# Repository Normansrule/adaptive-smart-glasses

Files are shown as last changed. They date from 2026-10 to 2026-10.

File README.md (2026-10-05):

<div align="center">

# 👓 Adaptive Smart Glasses <sup>v0.2</sup>

**Open-source camera-passthrough glasses you can print on a Bambu Lab P1S: a center camera, outward "design" screens, and inner micro-OLED screens.**

    

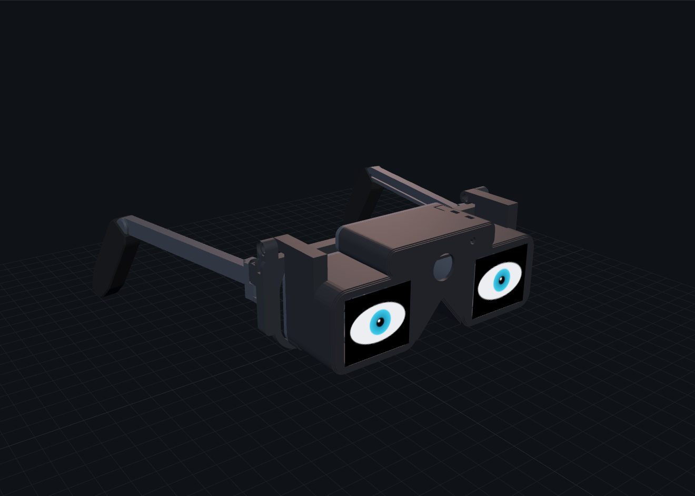
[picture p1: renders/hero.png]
Glasses with the eyes design


**[▶ 3D web app + phone controls](#-web-app--phone-controls)** · [3D files](cad/) · [BOM](docs/BOM.md) · [Pin-by-pin](docs/pinout.md) · [Build guide](docs/manufacturing.md) · [Requirements](docs/requirements.md)

</div>

---

## The idea (Apple Vision Pro meets Google glasses, in a glasses-sized prototype)

| 🎨 Outside: design screens | 👁️ Inside: you see through the camera | 📷 Center camera | 🔋 Light on the face |
|---|---|---|---|
| Two 1.69″ screens on the front show eyes, patterns, rainbow or scrolling text. You pick them from your phone. | Two 0.71″ 1080p micro-OLEDs show the camera view with AR help: zoom, edge highlight, low-light boost, a horizon line and a heads-up display (HUD). | 12 MP, 102° wide, in the bridge. It has a **hardware** power switch and a red **CAMERA LIVE** light. | Heavy compute runs in a **pocket brick** (Raspberry Pi 5) or on the phone. Batteries sit in the **earpieces** as a counterweight. |

| Visor down: passthrough | Visor up: plain glasses |
|---|---|
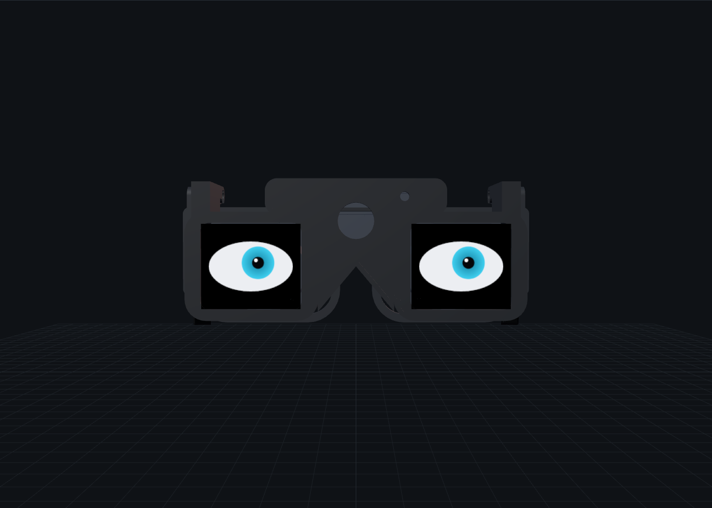
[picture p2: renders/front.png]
front
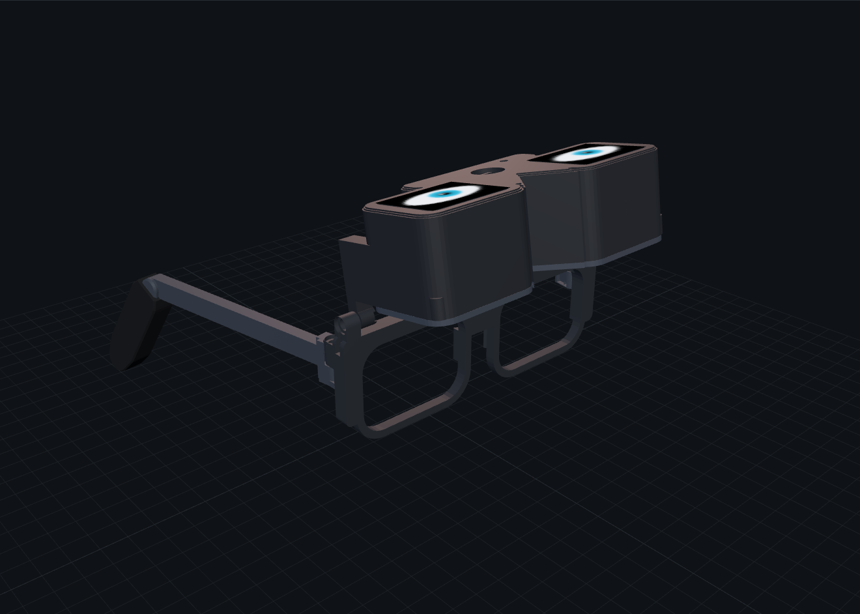
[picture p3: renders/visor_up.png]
visor up
|  |  |

The visor **flips up** on the brow hinge. That's the safety exit: with it up you see normally, and the inner screens switch off.

## Where everything goes

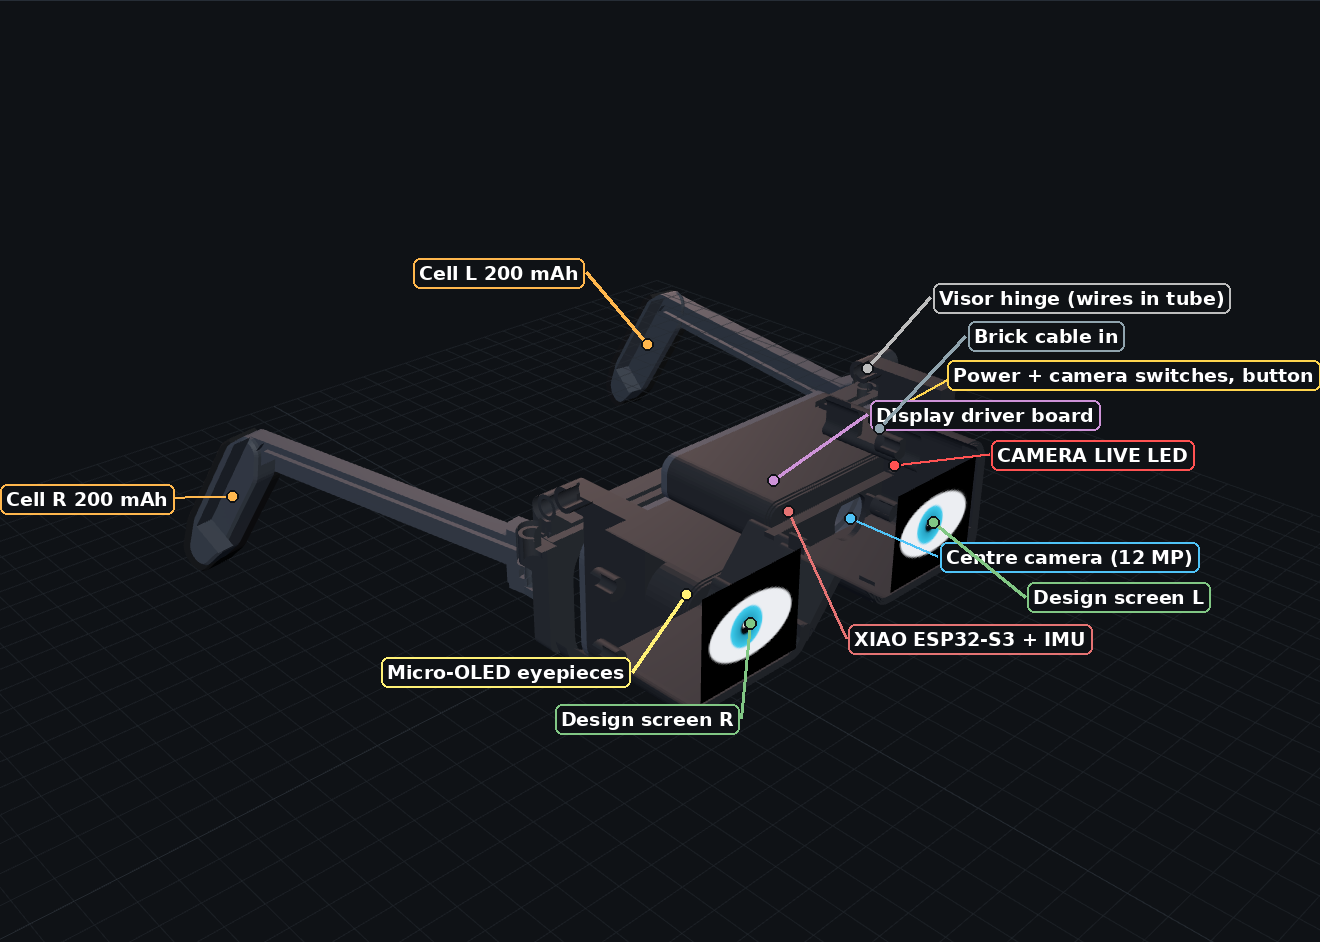
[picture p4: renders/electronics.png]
Electronics map


```
 phone (Web Bluetooth) ──BLE──►  XIAO ESP32-S3 (visor) ──SPI──► 2 outward design screens
                                   │ IMU, hall sensor, button, battery
                                   └──Wi-Fi UDP (head pose, AR mode)──┐
 camera (USB) ───────────────────────────────────────────────────────►├─► pocket brick (Pi 5)
 2 micro-OLEDs + HDMI board ◄────────── HDMI side-by-side 3840×1080 ──┘    passthrough + AR overlay
 earpiece cells (2 × 200 mAh) ──► XIAO  ·  brick power bank ──USB 5 V──► camera + display board
```

## Build it

| Step | What | Details |
|:-:|---|---|
| 1 | 🖨️ **Print** the coupon, tune, then plates 1–3 (7 parts, no supports) | [`cad/plates/`](cad/plates) · [print settings](cad/print_manifest.csv) |
| 2 | 🧪 **Bench test:** flash the XIAO and check the self-test and the designs on both screens | [`firmware/glasses_mcu`](firmware/glasses_mcu) |
| 3 | 🧠 **Brick:** run passthrough on a monitor first | [`brick/`](brick) |
| 4 | 🔭 **Optics** *(experimental)*: micro-OLED kit at side-by-side 3840×1080, then set focus and eye relief | [manufacturing §4](docs/manufacturing.md) |
| 5 | 🧩 **Assemble:** visor, 4 brass hinge tubes, earpiece cells, grips | [assembly](docs/README_CAD.md) |
| 6 | ✅ **Safety + QA:** unplug the camera and you should get a red screen in under 0.25 s; flip the visor up and the screens go dark | [QA sheet](docs/manufacturing.md) |

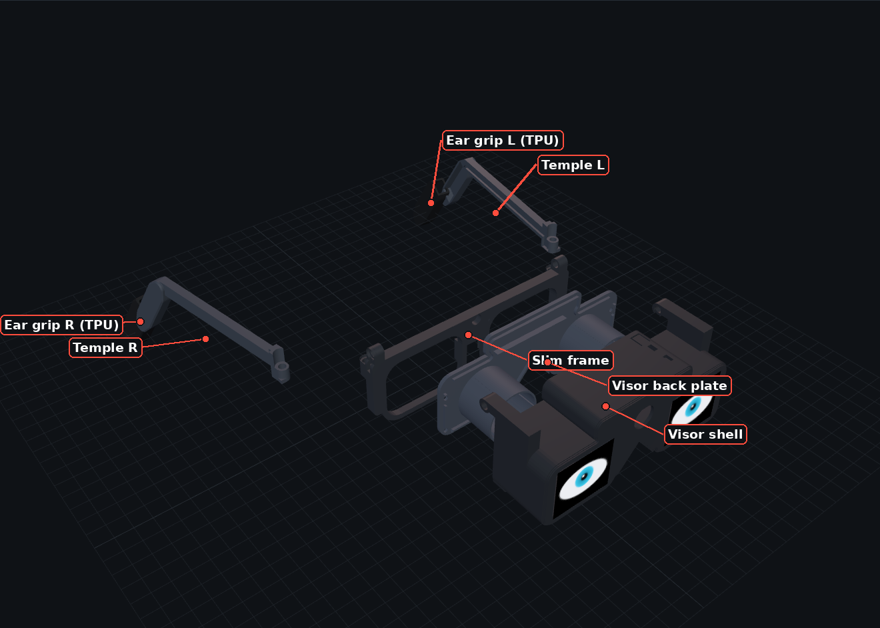
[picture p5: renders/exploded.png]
Exploded view


## Wiring (every pin: [`docs/pinout.md`](docs/pinout.md) · machine-readable: [`hardware/netlist.csv`](hardware/netlist.csv))

<details open><summary><b>Power + camera privacy</b></summary>

Power wiring
</details>
<details><summary><b>Signals: screens, camera, sensors</b></summary>

Signal wiring
</details>

| XIAO pin | Net | | XIAO pin | Net |
|---|---|---|---|---|
| D0 / D1 | CS left / right screen | | D6 | screen backlight (PWM) |
| D2 | screen DC (shared) | | D7 | visor hall switch |
| D3 | battery sense ½ | | D8 / D10 | SPI clock / data (shared) |
| D4 / D5 | I²C → IMU | | D9 | action button |

## Printed parts (7 + coupon)

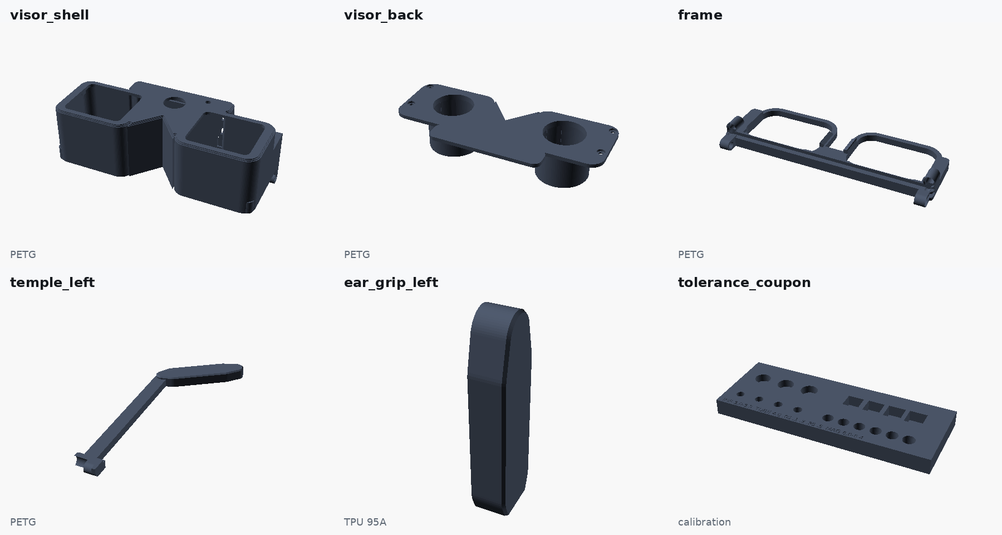
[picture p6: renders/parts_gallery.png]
Parts gallery


| Plate | Parts | Material |
|---|---|---|
| [`plate_0`](cad/plates/plate_0_tolerance_coupon.3mf) | Tolerance coupon (print first) | PETG |
| [`plate_1`](cad/plates/plate_1_frame_temples_petg.3mf) | Slim frame, 2 temples | PETG |
| [`plate_2`](cad/plates/plate_2_visor_petg.3mf) | Visor shell, visor back plate | black PETG |
| [`plate_3`](cad/plates/plate_3_tpu_grips.3mf) | 2 ear grips (they also close the battery bays) | TPU 95A |

## Bill of Materials (BOM)

| Group | ≈ Cost | Main parts |
|---|---:|---|
| **Glasses** | **$854** | 0.71″ 1080p micro-OLED dual kit with eyepieces ($660) · 2× Waveshare 1.69″ screens · Arducam 12 MP USB camera · XIAO ESP32-S3 · LSM6DSOX IMU · hall switch + magnet · 2× 200 mAh cells · 2 slide switches, button, LED · brass tubes, inserts, cable |
| **Pocket brick** | **$220** | Raspberry Pi 5 · 2-port power bank · microSD |
| **Phone** | $0 | Chrome + this repo's web app |

Full list with links: [`docs/BOM.md`](docs/BOM.md). A cheaper 0.49″ display route is listed as an option.

## Honest status

| Part | Status |
|---|---|
| Printed parts | 🟢 **PROTOTYPE-READY**: watertight, no collisions down or up, temples fold, no supports |
| Visor firmware (designs, BLE, IMU, Wi-Fi) | 🟢 compiles cleanly (ESP-IDF 5.5), not yet run on hardware |
| Brick passthrough | 🟡 **EXPERIMENTAL**: pipeline tested with synthetic frames. Expect 60–120 ms latency at 30 fps, mono (same image to both eyes) |
| Optics fit | 🟡 **EXPERIMENTAL**: eyepiece and driver-board sizes are `[MEASURE]` in [`cad/config.scad`](cad/config.scad) |
| Weight | ≈ 150 g (about 60 g printed + 90 g electronics). That's lighter than a headset but heavier than glasses (25–50 g). |

> ⚠️ **Passthrough safety:** with the visor down, you see only what the camera shows. Use it seated or walking slowly. **Never drive, cycle or use stairs with the visor down.** If the camera stalls, the brick shows a red **LIFT VISOR** screen. The camera can't be turned on in software, and the CAMERA LIVE light can't be hidden. Respect people around you.

## 🌐 Web app + phone controls

GitHub Pages hosts the 3D viewer (explode view, visor flip, live design preview, downloads, BOM, wiring) and a **Glasses** tab. In Chrome it uses Web Bluetooth to change the designs, text, brightness and AR mode on the real glasses. Click **Install app** to use it offline. Run it locally with `python3 -m http.server 8000`.

## Edit and rebuild

```bash
sudo apt install -y openscad python3 zip
nano cad/config.scad                 # IPD, head width, module sizes, tolerances
./tools/build.sh                     # STL, 3MF, plates, viewer meshes, BOM, netlist, diagrams
python3 tools/check_fit.py           # collision checks: visor down/up, temple fold
./tools/package_release.sh v0.2.1    # fabrication zip for a GitHub release
```

Licences: hardware **CERN-OHL-S-2.0**, software **MIT**, docs **CC BY-SA 4.0** ([`LICENSES/`](LICENSES/README.md)). The v0.1 camera-free design is in the git history and the v0.1.0 release.

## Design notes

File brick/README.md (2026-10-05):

# Pocket brick: Raspberry Pi 5 (EXPERIMENTAL)

```
camera (USB) ─► passthrough.py ─► enhance (normal / zoom / edges / low-light) ─► HUD ─► SBS 3840×1080 ─► HDMI ─► visor
visor XIAO ──Wi-Fi UDP :5005 (head pose, battery, visor state, AR mode)──► passthrough.py
```

```bash
bash brick/setup_brick.sh          # OpenCV + "ASG-BRICK" hotspot (password glasses123, gateway 10.42.0.1)
python3 brick/passthrough.py       # fullscreen on the HDMI output; press q to quit
python3 brick/passthrough.py --demo --frames 30 --out test.png   # no hardware: synthetic check
```

**Fail-safes:**
- No camera frame for 250 ms: red **LIFT VISOR** screen.
- Visor up: black screen.

**Privacy:** nothing is saved, and there is no face recognition. Expect 60–120 ms latency. Use it seated first.

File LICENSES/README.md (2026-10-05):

# Licensing

| What | Licence | Files |
|---|---|---|
| Hardware design | **CERN-OHL-S-2.0** (strongly reciprocal: modified versions must stay open) | `cad/`, `hardware/`, `models/`, `renders/` |
| Software | **MIT** | `firmware/`, `brick/`, `tools/`, `app.js`, `index.html`, `style.css`, `sw.js` |
| Documentation | **CC BY-SA 4.0** | `docs/`, `README.md` |
| three.js (vendored) | MIT, © three.js authors | `vendor/three/` |

Third-party modules in the BOM (Seeed, SparkFun, Adafruit, Bosch, Edmund Optics …) belong to their makers. This project only references them.

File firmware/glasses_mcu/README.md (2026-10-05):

# Visor firmware: XIAO ESP32-S3 (ESP-IDF 5.5)

| Feature | File |
|---|---|
| Two outward design screens (eyes, rings, rainbow, scrolling text, off), rendered in 40-line bands over SPI | `main/designs.c` |
| Phone control over BLE: GATT service `7a1e0000-5c3b-4c55-9b1d-a5e0a5e0a5e0` | `main/ble.c` |
| Head pose and state to the brick: Wi-Fi to the `ASG-BRICK` hotspot, UDP 44-byte packets at 100 Hz | `main/net.c` |
| IMU (LSM6DSOX), visor hall switch, action button, battery sense, boot self-test | `main/main.c` |

**Status:** compiles cleanly against ESP-IDF v5.5.1 for the esp32s3. Not yet run on finished hardware. The screen mirroring (`esp_lcd_panel_mirror`) and IMU axis signs need checking on the bench.

**Flash the prebuilt image** (no toolchain needed):
```bash
pip install esptool
esptool.py --chip esp32s3 write_flash 0x0 prebuilt/asg_glasses_mcu_merged.bin
```

**Build from source:**
```bash
. ~/esp/esp-idf-v5.5.5/export.sh          # or your ESP-IDF 5.5 path
idf.py set-target esp32s3
idf.py menuconfig    # optional: "Adaptive Smart Glasses" menu (hotspot SSID/password, brick IP/port)
idf.py build flash monitor
```

**Button:** a short press cycles designs. Hold it for at least 1 s to turn the designs off.

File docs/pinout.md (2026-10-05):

# Pin-by-pin connections

Generated by `tools/netlist.py` from the same table as `hardware/netlist.csv` and the diagrams. Edit the script, not this file.

Power and privacy wiring

Signal wiring

## Board prep (do this before wiring)

| Ref | Pin / item | Action |
|---|---|---|
| U5 | RST | tie to 3V3 (the firmware sends a software reset) |
| U6 | RST | tie to 3V3 |
| U1 | D3 | ADC: VBAT/2 |
| U7 | 5V in | power the HDMI board from VBUS, never from the XIAO 3V3 |
| BT1 | before joining | charge both cells to 4.2 V separately, then wire them in parallel |

## Every module, every pin

### J1 · Brick cable
*micro-HDMI->HDMI + USB 4-core, braided* · Enters visor crest, left side

| Pin | Net | Connects to | Wire |
|---|---|---|---|
| USB VBUS | `VBUS_5V` | D2.anode, SW2.COM, U7.5V in | USB red |
| USB GND / HDMI shell | `GND` | BT1.-, BT2.-, U1.GND + BAT- pad, R3.2, D1.cathode, U2.GND, U3.GND, U4.GND, U5.GND, U6.GND, U7.GND, SW3.pin 2 | 28 AWG black |
| USB D+ | `USB_D+` | U2.D+ | USB green |
| USB D- | `USB_D-` | U2.D- | USB white |
| HDMI | `HDMI` | U7.HDMI in | HDMI cable |

### BT1 · Cell LEFT
*Protected 1S LiPo 501040 200 mAh* · Left earpiece

| Pin | Net | Connects to | Wire |
|---|---|---|---|
| + | `BAT+` | BT2.+, SW1.COM | 28 AWG red |
| - | `GND` | BT2.-, J1.USB GND / HDMI shell, U1.GND + BAT- pad, R3.2, D1.cathode, U2.GND, U3.GND, U4.GND, U5.GND, U6.GND, U7.GND, SW3.pin 2 | 28 AWG black |

### BT2 · Cell RIGHT
*Protected 1S LiPo 501040 200 mAh* · Right earpiece

| Pin | Net | Connects to | Wire |
|---|---|---|---|
| + | `BAT+` | BT1.+, SW1.COM | 28 AWG red |
| - | `GND` | BT1.-, J1.USB GND / HDMI shell, U1.GND + BAT- pad, R3.2, D1.cathode, U2.GND, U3.GND, U4.GND, U5.GND, U6.GND, U7.GND, SW3.pin 2 | 28 AWG black |

### SW1 · Main power
*Wurth 452403012014 DPDT slide* · Visor crest top

| Pin | Net | Connects to | Wire |
|---|---|---|---|
| COM | `BAT+` | BT1.+, BT2.+ | 28 AWG red |
| throw A | `BAT_SW` | U1.BAT+ pad, R2.1 | local |

### SW2 · Camera kill
*Wurth 452403012014 DPDT slide* · Visor crest top

| Pin | Net | Connects to | Wire |
|---|---|---|---|
| COM | `VBUS_5V` | J1.USB VBUS, D2.anode, U7.5V in | USB red |
| throw A | `CAM_5V` | U2.5V (USB VBUS), R1.1 | local |

### D1 · CAMERA LIVE LED
*3 mm red LED* · Visor front, beside camera

| Pin | Net | Connects to | Wire |
|---|---|---|---|
| anode (long leg) | `LED_A` | R1.2 | local |
| cathode | `GND` | BT1.-, BT2.-, J1.USB GND / HDMI shell, U1.GND + BAT- pad, R3.2, U2.GND, U3.GND, U4.GND, U5.GND, U6.GND, U7.GND, SW3.pin 2 | 28 AWG black |

### R1 · 1k
*1k 1/8 W* · Visor crest

| Pin | Net | Connects to | Wire |
|---|---|---|---|
| 1 | `CAM_5V` | SW2.throw A, U2.5V (USB VBUS) | local |
| 2 | `LED_A` | D1.anode (long leg) | local |

### D2 · 1N5817
*1N5817 Schottky* · Visor crest

| Pin | Net | Connects to | Wire |
|---|---|---|---|
| anode | `VBUS_5V` | J1.USB VBUS, SW2.COM, U7.5V in | USB red |
| cathode (band) | `XIAO_5V` | U1.5V | local |

### U1 · XIAO ESP32-S3
*Seeed XIAO ESP32-S3 (non-Sense)* · Visor bridge, behind camera

| Pin | Net | Connects to | Wire |
|---|---|---|---|
| BAT+ pad | `BAT_SW` | SW1.throw A, R2.1 | local |
| D3 (A2) | `VBAT_DIV` | R2.2, R3.1 | local |
| 5V | `XIAO_5V` | D2.cathode (band) | local |
| GND + BAT- pad | `GND` | BT1.-, BT2.-, J1.USB GND / HDMI shell, R3.2, D1.cathode, U2.GND, U3.GND, U4.GND, U5.GND, U6.GND, U7.GND, SW3.pin 2 | 28 AWG black |
| 3V3 | `3V3` | U3.VIN (Qwiic), U4.VCC, U5.VCC + RST, U6.VCC + RST | local |
| D8 | `SPI_SCK` | U5.CLK, U6.CLK | local |
| D10 | `SPI_MOSI` | U5.DIN, U6.DIN | local |
| D2 | `LCD_DC` | U5.DC, U6.DC | local |
| D0 | `CS_L` | U5.CS | local |
| D1 | `CS_R` | U6.CS | local |
| D6 | `LCD_BL` | U5.BL, U6.BL | local |
| D4 | `SDA` | U3.SDA (Qwiic) | Qwiic blue |
| D5 | `SCL` | U3.SCL (Qwiic) | Qwiic yellow |
| D7 | `HALL` | U4.OUT | local |
| D9 | `BUTTON` | SW3.pin 1 | local |

### R2 · 100k top
*100k 1/8 W* · Visor bridge

| Pin | Net | Connects to | Wire |
|---|---|---|---|
| 1 | `BAT_SW` | SW1.throw A, U1.BAT+ pad | local |
| 2 | `VBAT_DIV` | R3.1, U1.D3 (A2) | local |

### R3 · 100k bottom
*100k 1/8 W* · Visor bridge

| Pin | Net | Connects to | Wire |
|---|---|---|---|
| 1 | `VBAT_DIV` | R2.2, U1.D3 (A2) | local |
| 2 | `GND` | BT1.-, BT2.-, J1.USB GND / HDMI shell, U1.GND + BAT- pad, D1.cathode, U2.GND, U3.GND, U4.GND, U5.GND, U6.GND, U7.GND, SW3.pin 2 | 28 AWG black |

### U2 · Camera
*Arducam IMX708 UVC 102 deg* · Visor centre bridge, front

| Pin | Net | Connects to | Wire |
|---|---|---|---|
| 5V (USB VBUS) | `CAM_5V` | SW2.throw A, R1.1 | local |
| GND | `GND` | BT1.-, BT2.-, J1.USB GND / HDMI shell, U1.GND + BAT- pad, R3.2, D1.cathode, U3.GND, U4.GND, U5.GND, U6.GND, U7.GND, SW3.pin 2 | 28 AWG black |
| D+ | `USB_D+` | J1.USB D+ | USB green |
| D- | `USB_D-` | J1.USB D- | USB white |

### U3 · IMU
*Adafruit 4438 LSM6DSOX* · Visor bridge

| Pin | Net | Connects to | Wire |
|---|---|---|---|
| GND | `GND` | BT1.-, BT2.-, J1.USB GND / HDMI shell, U1.GND + BAT- pad, R3.2, D1.cathode, U2.GND, U4.GND, U5.GND, U6.GND, U7.GND, SW3.pin 2 | 28 AWG black |
| VIN (Qwiic) | `3V3` | U1.3V3, U4.VCC, U5.VCC + RST, U6.VCC + RST | local |
| SDA (Qwiic) | `SDA` | U1.D4 | Qwiic blue |
| SCL (Qwiic) | `SCL` | U1.D5 | Qwiic yellow |

### U4 · Hall switch
*TI DRV5032FA on SOT-23 adapter* · Back of visor bridge, faces brow magnet

| Pin | Net | Connects to | Wire |
|---|---|---|---|
| GND | `GND` | BT1.-, BT2.-, J1.USB GND / HDMI shell, U1.GND + BAT- pad, R3.2, D1.cathode, U2.GND, U3.GND, U5.GND, U6.GND, U7.GND, SW3.pin 2 | 28 AWG black |
| VCC | `3V3` | U1.3V3, U3.VIN (Qwiic), U5.VCC + RST, U6.VCC + RST | local |
| OUT | `HALL` | U1.D7 | local |

### U5 · LCD LEFT
*Waveshare 1.69in 240x280 ST7789V2* · Left pod, front

| Pin | Net | Connects to | Wire |
|---|---|---|---|
| GND | `GND` | BT1.-, BT2.-, J1.USB GND / HDMI shell, U1.GND + BAT- pad, R3.2, D1.cathode, U2.GND, U3.GND, U4.GND, U6.GND, U7.GND, SW3.pin 2 | 28 AWG black |
| VCC + RST | `3V3` | U1.3V3, U3.VIN (Qwiic), U4.VCC, U6.VCC + RST | local |
| CLK | `SPI_SCK` | U1.D8, U6.CLK | local |
| DIN | `SPI_MOSI` | U1.D10, U6.DIN | local |
| DC | `LCD_DC` | U1.D2, U6.DC | local |
| CS | `CS_L` | U1.D0 | local |
| BL | `LCD_BL` | U1.D6, U6.BL | local |

### U6 · LCD RIGHT
*Waveshare 1.69in 240x280 ST7789V2* · Right pod, front

| Pin | Net | Connects to | Wire |
|---|---|---|---|
| GND | `GND` | BT1.-, BT2.-, J1.USB GND / HDMI shell, U1.GND + BAT- pad, R3.2, D1.cathode, U2.GND, U3.GND, U4.GND, U5.GND, U7.GND, SW3.pin 2 | 28 AWG black |
| VCC + RST | `3V3` | U1.3V3, U3.VIN (Qwiic), U4.VCC, U5.VCC + RST | local |
| CLK | `SPI_SCK` | U1.D8, U5.CLK | local |
| DIN | `SPI_MOSI` | U1.D10, U5.DIN | local |
| DC | `LCD_DC` | U1.D2, U5.DC | local |
| CS | `CS_R` | U1.D1 | local |
| BL | `LCD_BL` | U1.D6, U5.BL | local |

### U7 · Micro-OLED board
*Dual 0.71in micro-OLED HDMI driver* · Visor crest bay

| Pin | Net | Connects to | Wire |
|---|---|---|---|
| 5V in | `VBUS_5V` | J1.USB VBUS, D2.anode, SW2.COM | USB red |
| GND | `GND` | BT1.-, BT2.-, J1.USB GND / HDMI shell, U1.GND + BAT- pad, R3.2, D1.cathode, U2.GND, U3.GND, U4.GND, U5.GND, U6.GND, SW3.pin 2 | 28 AWG black |
| HDMI in | `HDMI` | J1.HDMI | HDMI cable |
| FPC L / FPC R | `OLED_FPC` | test pad / no connection | panel flex |

### SW3 · Action button
*Omron B3F-1000 6x6 tact* · Visor crest top flexure

| Pin | Net | Connects to | Wire |
|---|---|---|---|
| pin 2 | `GND` | BT1.-, BT2.-, J1.USB GND / HDMI shell, U1.GND + BAT- pad, R3.2, D1.cathode, U2.GND, U3.GND, U4.GND, U5.GND, U6.GND, U7.GND | 28 AWG black |
| pin 1 | `BUTTON` | U1.D9 | local |

## Harness cut list (wires that cross a hinge)

| Signal | Wire | Cut (mm) | Route |
|---|---|---:|---|
| BAT+ / GND (left cell) | 30 AWG red/black | 230 | BT1 -> earpiece groove -> L temple tube -> frame -> L visor tube -> SW1 |
| BAT+ / GND (right cell) | 30 AWG red/black | 330 | BT2 -> R temple tube -> brow groove -> L visor tube -> SW1 |
| Brick cable | HDMI + USB 4-core | 1500 | Pocket brick -> clip along left temple -> visor crest (left side) |
| LCD harness | 8 x 30 AWG | 120 | U1 (bridge) -> U5 and U6 (shared SCK/MOSI/DC/BL/VCC/GND, own CS) |

Only battery wires cross hinges: each temple tube carries its cell's BAT+ and GND (2 wires), and the left visor tube carries both pairs (4 wires). Everything else lives inside the visor.

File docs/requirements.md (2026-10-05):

# Requirements and verification (v0.2)

Method: **I** = inspection · **A** = analysis/CAD · **T** = test.
Status: ✅ verified in CAD/analysis/compile · 🧪 needs a hardware test · ⏳ not built yet.

> v0.2 deliberately replaces the v0.1 "camera-free" rule (owner's decision, 2026-10). The privacy rules below take its place.

## Privacy
| ID | Requirement | Method | How it's met | Status |
|---|---|---|---|---|
| PRV-1 | The camera can only get power from a physical switch | I/T | SW2 is the only path from VBUS to CAM_5V ([pinout](pinout.md)). Test: SW2 off means the brick sees no USB camera. | 🧪 |
| PRV-2 | The CAMERA LIVE light is on whenever the camera has power, and software can't hide it | A/T | D1 + R1 sit on CAM_5V and nowhere else. | ✅ wiring · 🧪 |
| PRV-3 | No face recognition, and no recording by default | I | `brick/passthrough.py` processes frames in memory and drops them. | ✅ |
| PRV-4 | Outward designs can be turned off at once | T | Long-press the button, or choose Off in the app. Backlight goes to 0. | 🧪 |

## Safety
| ID | Requirement | Method | How it's met | Status |
|---|---|---|---|---|
| SAF-1 | One action restores normal vision | A/T | The visor flips up through 100° with no collisions (`tools/check_fit.py`), and the frame has open lenses. | ✅ CAD · 🧪 |
| SAF-2 | If the camera fails or stalls, warn within 250 ms | T | The brick shows a red LIFT VISOR screen after 250 ms with no frame. | ✅ synthetic · 🧪 |
| SAF-3 | Visor up turns the inner and outer screens off | T | Hall switch (D7) → firmware blanks the designs; the UDP flag → brick shows black. | ✅ code · 🧪 |
| SAF-4 | Never use passthrough while driving, cycling or on stairs | I | README + app warning. Owner's responsibility. | ✅ doc |
| SAF-5 | Battery safety | A/T | Protected cells at 0.25C charge (XIAO 100 mA), away from the skin behind a 1.4 mm wall + TPU grip. | 🧪 |
| SAF-6 | Design animations stay under 3 flashes per second (photosensitivity) | A | Rings ≈ 0.8 Hz, rainbow is a smooth drift, the eyes blink about every 3–5 s. | ✅ |
| SAF-7 | No sharp edges against the skin | I | Chamfered visor, TPU grips, nose pads. Deburr the tubes. | 🧪 |

## Manufacturability
| ID | Requirement | Method | Status |
|---|---|---|---|
| MFG-1 | All parts print on a P1S with no supports | A (`cad/part_stats.json`) | ✅ |
| MFG-2 | All meshes are manifold | A (`tools/postprocess.py`) | ✅ |
| MFG-3 | No collisions: visor at 0/35/70/100°, temple folded to 80° | A (`tools/check_fit.py`) | ✅ |
| MFG-4 | Only battery wires cross hinges, through the brass tubes | A ([pinout](pinout.md)) | ✅ |
| MFG-5 | Firmware builds from a clean checkout | T (`idf.py build`, ESP-IDF 5.5.1) | ✅ |
| MFG-6 | Optics and driver-board pockets match the real parts | I (`[MEASURE]`) | 🧪 |

## Performance targets
| ID | Target | Status |
|---|---|---|
| PRF-1 | Passthrough at ≥ 30 fps, latency ≤ 120 ms (measure by filming a stopwatch through the eyepiece) | 🧪 |
| PRF-2 | Design screens at ≥ 15 fps on both | 🧪 |
| PRF-3 | Head pose to the brick at 100 Hz | ✅ code · 🧪 |
| PRF-4 | Designs-only standby ≥ 1 h on the earpiece cells | 🧪 |

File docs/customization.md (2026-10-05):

# Customization (`cad/config.scad`)

| Parameter | Default | What it does |
|---|---|---|
| `ipd` | 63 | Pupil distance: centers both eyepiece sleeves. **Set this to your own.** |
| `eye_relief` | 17 | Eye-to-eyepiece distance. The visor position follows it. |
| `head_width`, `ear_y`, `ear_droop` | 148, 98, 55° | Temple splay, ear bend, earpiece angle |
| `cell` | [40, 10, 5] | Earpiece battery bay (L × W × T). For an LP401235, use [36, 12, 4]. |
| `eyepiece_d`, `eyepiece_len` | 26, 22 | **[MEASURE]** your eyepieces |
| `hdmi_board` | [45, 28, 7] | **[MEASURE]** the dual micro-OLED driver board |
| `lcd`, `lcd_active` | 39 × 31.5, 32.6 × 28 | Waveshare 1.69″ screen (outline confirmed, thickness [MEASURE]) |
| `cam_board`, `cam_lens_d`, `cam_z` | 24 × 25, 12, 16.4 | Arducam IMX708 UVC board and lens hole |
| `visor_tube_run` | 4.2 | Frame-side visor bore. Smaller means stiffer (holds the visor up). Tune it on the coupon. |
| `visor_up_deg` | 100 | Flip angle checked by `tools/check_fit.py` |
| `tol`, `insert_hole_d`, `tube_hole_glue`, `tube_hole_run` | 0.3, 3.1, 4.05, 4.35 | Print fits. Tune on the coupon. |

After any change, run `./tools/build.sh && python3 tools/check_fit.py`.

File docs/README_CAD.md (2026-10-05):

# CAD: build, print, assemble (v0.2)

Source: `cad/adaptive_smart_glasses.scad` + `cad/config.scad`.
Outputs: `cad/stl/`, `cad/3mf/`, `cad/plates/`, `models/` (web viewer), `cad/part_stats.json`.

```bash
./tools/build.sh                 # all parts (~1 min)
python3 tools/check_fit.py       # collision checks: visor 0/35/70/100 deg, temple fold, shell vs back plate
openscad -D 'part="assembly_up"' cad/adaptive_smart_glasses.scad   # visor-up preview
```

## Parts
| Part | Material | Print orientation | Holds |
|---|---|---|---|
| frame | PETG | front face down | nose pads, temple + visor hinge knuckles, hall magnet |
| temple_left / temple_right | PETG | head face down | slim arm, earpiece battery bay |
| ear_grip_left / ear_grip_right | TPU 95A | entry end down | closes the battery bay, comfort |
| visor_shell | black PETG | front face down | 2 design screens, camera + LED, crest controls, bridge electronics, visor knuckles |
| visor_back | black PETG | eye side down | eyepiece sleeves (at your IPD), driver-board rail |
| tolerance_coupon | PETG | flat | fit tests |

## Checked in CAD
- All parts are watertight and print with no supports.
- No collisions at rest, with the visor at 35, 70 and 100 degrees, or with a temple folded to 80 degrees.
- The visor clears the frame through its whole travel. The hinge axis sits on top of the brow (Y = +3.3 mm, Z = 27.5 mm).

## Hinges
- **Temples:** a vertical brass-tube pin, with that side's cell wires inside it.
- **Visor:** a horizontal brass-tube pin along X at each end.
  - The tube is glued in the visor knuckle and turns snugly in the frame knuckle (4.2 mm bore), so friction holds the visor up.
  - The left tube carries all 4 battery wires.

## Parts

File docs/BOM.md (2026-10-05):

# Bill of Materials (BOM)

Generated from [`../bom.csv`](../bom.csv) by `tools/bom_md.py`. Prices are approximate USD, so verify before ordering.
Status labels: **FINISHED / PROTOTYPE-READY / EXPERIMENTAL**.

## GLASSES ≈ $853.74

| Item | Part | Qty | ≈ $ each | Status | Notes | Change vs brief |
|---|---|---:|---:|---|---|---|
| [0.71in 1920x1080 micro-OLED 3D dual kit: 2 panels + 1 HDMI board for both + 2 OPE07-10X prism eyepieces](https://www.tindie.com/products/microdisplays/micro-oled-dual-display-071-fhd-1080p-1920x1080/) | Sony ECX335S dual kit | 1 | 659.50 | EXPERIMENTAL | One HDMI input drives both eyes, side by side. Panel is 24.24 x 15.62 x 1.54 mm. Measure the optics and board, then set eyepiece_d, eyepiece_len and hdmi_board in config.scad. | NEW: passthrough view |
| [1.69in 240x280 IPS LCD, ST7789V2, SPI](https://www.waveshare.com/1.69inch-lcd-module.htm) | Waveshare 1.69inch LCD Module | 2 | 9.49 | PROTOTYPE-READY | Shows the designs on the front of each lens. 39 x 31.5 mm outline, about 90 mA each. | NEW: designs screens |
| [12MP IMX708 USB UVC camera, 102 deg (120 deg diagonal), fixed focus](https://www.arducam.com/12mp-imx708-usb-uvc-102-wide-angle-fixed-focus-camera-module-3.html) | Arducam IMX708 UVC 102 | 1 | 71.98 | PROTOTYPE-READY | 24 x 25 mm board in the centre bridge. 1080p30 MJPEG for passthrough, 12 MP stills. For 60 fps you need a 38 mm board. | NEW: centre camera |
| [Seeed XIAO ESP32-S3 (non-Sense)](https://wiki.seeedstudio.com/xiao_esp32s3_getting_started/) | XIAO ESP32-S3 | 1 | 7.49 | PROTOTYPE-READY | Drives the outward LCDs, IMU, hall sensor, button, battery sense and LiPo charging. BLE to the phone, Wi-Fi to the brick. | kept |
| [LSM6DSOX 6-DoF IMU, STEMMA QT](https://www.adafruit.com/product/4438) | Adafruit 4438 | 1 | 11.95 | PROTOTYPE-READY | Mounted in the visor bridge, rigid with the displays. | kept |
| [Hall switch, omnipolar, 1.65-5.5 V](https://www.lcsc.com/product-detail/hall-switches_ti-drv5032fadbzr_C140921.html) | TI DRV5032FA (SOT-23) on a SOT-23 adapter | 1 | 1.20 | PROTOTYPE-READY | Detects visor up or down using a magnet in the brow. Visor up turns the inner displays off and blanks the designs. | NEW |
| Neodymium disc magnet 6 x 3 mm N52 | 6x3 N52 | 1 | 0.30 | PROTOTYPE-READY | Press-fit into the brow centre. | NEW |
| [Protected 1S LiPo 5 x 10 x 40 mm, ~200 mAh (or LP401235 4x12x36)](https://www.ebay.com/itm/254701205905) | 501040 PCM | 2 | 6.00 | PROTOTYPE-READY | One per earpiece, as a counterweight. Wired in parallel: charge both to 4.2 V before joining them. Standby only; passthrough runs on cable power. | 1 big cell -> 2 earpiece cells |
| [DPDT slide switch, 300 mA](https://www.mouser.com/c/?q=452403012014) | Wurth 452403012014 | 2 | 2.67 | PROTOTYPE-READY | Switch 1 is main battery power. Switch 2 is the camera power kill: it physically cuts the camera's 5 V supply. | NEW (camera privacy) |
| 3 mm red LED + 1k resistor on the camera 5 V (after the switch) | CAMERA LIVE | 1 | 0.25 | PROTOTYPE-READY | Hardware-tied, so software cannot hide it. It faces forward beside the camera. | NEW |
| [6 x 6 mm tactile switch](https://www.digikey.com/en/products/filter/pushbutton-switches/199) | Omron B3F-1000 | 1 | 0.25 | PROTOTYPE-READY | Action button under the crest flexure: cycle designs, long-press to capture. | kept |
| 2 x 100k (battery sense divider) | 100k | 2 | 0.03 | PROTOTYPE-READY |  | kept |
| [Brass tube 4 mm OD (ID 3.1), 300 mm](https://ksmetals.com/products/br45mm-4) | K&S 9822 | 1 | 9.99 | EXPERIMENTAL | Four 12-13.5 mm pins: 2 temple hinges, 2 visor hinges. Wires run through them. | kept |
| [M2 heat-set inserts + M2x6 screws](https://www.3djake.com/ruthex/threaded-insert-m2-70-pieces) | ruthex M2 x 4 | 1 | 8.50 | PROTOTYPE-READY | 4 inserts hold the back plate. | kept |
| Thin micro-HDMI to HDMI (1.5 m) + USB-A to bare-wire 4-core (1.5 m), braided sleeve |  | 1 | 18.00 | PROTOTYPE-READY | Video in to the HDMI board, plus USB carrying camera data and 5 V for the glasses. Enters the crest on the left side. | NEW |
| [Stick-on silicone nose pads](https://eyeglasssupplystore.com/products/adhesive-silicone-nose-pads) | adhesive D-pads | 1 | 15.95 | PROTOTYPE-READY |  | kept |
| Silicone wire 30 AWG, 1 mm foam tape, Kapton, filament (PETG ~80 g, TPU ~6 g) |  | 1 | 12.00 | PROTOTYPE-READY |  | kept |

## BRICK ≈ $220.00

| Item | Part | Qty | ≈ $ each | Status | Notes | Change vs brief |
|---|---|---:|---:|---|---|---|
| [Raspberry Pi 5 (8 GB) + active cooler](https://www.raspberrypi.com/products/raspberry-pi-5/) | Raspberry Pi 5 | 1 | 175.00 | EXPERIMENTAL | Runs camera passthrough plus the AR overlay, outputs side-by-side 3840x1080 over HDMI, and does local AI. A Pi 5 4 GB also works. | NEW (Vision Pro-style pocket brick) |
| USB-C power bank, 2 outputs, at least 5V/3A |  | 1 | 35.00 | PROTOTYPE-READY | Port 1 powers the Pi. Port 2 powers the glasses 5 V through the USB lead (keeps load off the Pi's 600 mA USB limit). | NEW |
| microSD 64 GB A2 |  | 1 | 10.00 | PROTOTYPE-READY | Raspberry Pi OS 64-bit + brick/ software. | kept |

## PHONE

| Item | Part | Qty | ≈ $ each | Status | Notes | Change vs brief |
|---|---|---:|---:|---|---|---|
| Any phone with Chrome (Android) for the Web Bluetooth controls |  | 0 | 0.00 | PROTOTYPE-READY | Designs, brightness, text and status via the web app's Glasses tab. Heavy AI can run on the phone or the brick. | NEW |

## OPTION

| Item | Part | Qty | ≈ $ each | Status | Notes | Change vs brief |
|---|---|---:|---:|---|---|---|
| [0.49in 1920x1080 micro-OLED + Dual HDMI or Dual Type-C board, x2](https://www.tindie.com/products/oled-modules/049-micro-oled-display-1920x1080-3000nits/) | SeeYA SY049-class | 0 | 135.00 | EXPERIMENTAL | Panel is 15.68 x 9.09 mm. The Dual Type-C board could take video straight from a DisplayPort-capable phone. Board price and size are unconfirmed. | option |

Totals: glasses ≈ $854 · pocket brick ≈ $220 · together ≈ $1074.
Most of the glasses cost is the micro-OLED dual kit ($660). The budget 0.49-inch option is listed under OPTION.

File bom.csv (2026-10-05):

subsystem | item | part_or_example | qty | approx_unit_usd | tier | status | engineering_notes | source_url | change_vs_brief
Inner displays | 0.71in 1920x1080 micro-OLED 3D dual kit: 2 panels + 1 HDMI board for both + 2 OPE07-10X prism eyepieces | Sony ECX335S dual kit | 1 | 659.5 | GLASSES | EXPERIMENTAL | One HDMI input drives both eyes, side by side. Panel is 24.24 x 15.62 x 1.54 mm. Measure the optics and board, then set eyepiece_d, eyepiece_len and hdmi_board in config.scad. | https://www.tindie.com/products/microdisplays/micro-oled-dual-display-071-fhd-1080p-1920x1080/ | NEW: passthrough view
Inner displays (budget) | 0.49in 1920x1080 micro-OLED + Dual HDMI or Dual Type-C board, x2 | SeeYA SY049-class | 0 | 135.0 | OPTION | EXPERIMENTAL | Panel is 15.68 x 9.09 mm. The Dual Type-C board could take video straight from a DisplayPort-capable phone. Board price and size are unconfirmed. | https://www.tindie.com/products/oled-modules/049-micro-oled-display-1920x1080-3000nits/ | option
Outward displays | 1.69in 240x280 IPS LCD, ST7789V2, SPI | Waveshare 1.69inch LCD Module | 2 | 9.49 | GLASSES | PROTOTYPE-READY | Shows the designs on the front of each lens. 39 x 31.5 mm outline, about 90 mA each. | https://www.waveshare.com/1.69inch-lcd-module.htm | NEW: designs screens
Camera | 12MP IMX708 USB UVC camera, 102 deg (120 deg diagonal), fixed focus | Arducam IMX708 UVC 102 | 1 | 71.98 | GLASSES | PROTOTYPE-READY | 24 x 25 mm board in the centre bridge. 1080p30 MJPEG for passthrough, 12 MP stills. For 60 fps you need a 38 mm board. | https://www.arducam.com/12mp-imx708-usb-uvc-102-wide-angle-fixed-focus-camera-module-3.html | NEW: centre camera
MCU | Seeed XIAO ESP32-S3 (non-Sense) | XIAO ESP32-S3 | 1 | 7.49 | GLASSES | PROTOTYPE-READY | Drives the outward LCDs, IMU, hall sensor, button, battery sense and LiPo charging. BLE to the phone, Wi-Fi to the brick. | https://wiki.seeedstudio.com/xiao_esp32s3_getting_started/ | kept
Head tracking | LSM6DSOX 6-DoF IMU, STEMMA QT | Adafruit 4438 | 1 | 11.95 | GLASSES | PROTOTYPE-READY | Mounted in the visor bridge, rigid with the displays. | https://www.adafruit.com/product/4438 | kept
Visor sensor | Hall switch, omnipolar, 1.65-5.5 V | TI DRV5032FA (SOT-23) on a SOT-23 adapter | 1 | 1.2 | GLASSES | PROTOTYPE-READY | Detects visor up or down using a magnet in the brow. Visor up turns the inner displays off and blanks the designs. | https://www.lcsc.com/product-detail/hall-switches_ti-drv5032fadbzr_C140921.html | NEW
Visor sensor | Neodymium disc magnet 6 x 3 mm N52 | 6x3 N52 | 1 | 0.3 | GLASSES | PROTOTYPE-READY | Press-fit into the brow centre. |  | NEW
Batteries | Protected 1S LiPo 5 x 10 x 40 mm, ~200 mAh (or LP401235 4x12x36) | 501040 PCM | 2 | 6.0 | GLASSES | PROTOTYPE-READY | One per earpiece, as a counterweight. Wired in parallel: charge both to 4.2 V before joining them. Standby only; passthrough runs on cable power. | https://www.ebay.com/itm/254701205905 | 1 big cell -> 2 earpiece cells
Power / privacy | DPDT slide switch, 300 mA | Wurth 452403012014 | 2 | 2.67 | GLASSES | PROTOTYPE-READY | Switch 1 is main battery power. Switch 2 is the camera power kill: it physically cuts the camera's 5 V supply. | https://www.mouser.com/c/?q=452403012014 | NEW (camera privacy)
Privacy indicator | 3 mm red LED + 1k resistor on the camera 5 V (after the switch) | CAMERA LIVE | 1 | 0.25 | GLASSES | PROTOTYPE-READY | Hardware-tied, so software cannot hide it. It faces forward beside the camera. |  | NEW
Input | 6 x 6 mm tactile switch | Omron B3F-1000 | 1 | 0.25 | GLASSES | PROTOTYPE-READY | Action button under the crest flexure: cycle designs, long-press to capture. | https://www.digikey.com/en/products/filter/pushbutton-switches/199 | kept
Power | 2 x 100k (battery sense divider) | 100k | 2 | 0.03 | GLASSES | PROTOTYPE-READY |  |  | kept
Hinges | Brass tube 4 mm OD (ID 3.1), 300 mm | K&S 9822 | 1 | 9.99 | GLASSES | EXPERIMENTAL | Four 12-13.5 mm pins: 2 temple hinges, 2 visor hinges. Wires run through them. | https://ksmetals.com/products/br45mm-4 | kept
Fasteners | M2 heat-set inserts + M2x6 screws | ruthex M2 x 4 | 1 | 8.5 | GLASSES | PROTOTYPE-READY | 4 inserts hold the back plate. | https://www.3djake.com/ruthex/threaded-insert-m2-70-pieces | kept
Cable | Thin micro-HDMI to HDMI (1.5 m) + USB-A to bare-wire 4-core (1.5 m), braided sleeve |  | 1 | 18.0 | GLASSES | PROTOTYPE-READY | Video in to the HDMI board, plus USB carrying camera data and 5 V for the glasses. Enters the crest on the left side. |  | NEW
Comfort | Stick-on silicone nose pads | adhesive D-pads | 1 | 15.95 | GLASSES | PROTOTYPE-READY |  | https://eyeglasssupplystore.com/products/adhesive-silicone-nose-pads | kept
Consumables | Silicone wire 30 AWG, 1 mm foam tape, Kapton, filament (PETG ~80 g, TPU ~6 g) |  | 1 | 12.0 | GLASSES | PROTOTYPE-READY |  |  | kept
Brick compute | Raspberry Pi 5 (8 GB) + active cooler | Raspberry Pi 5 | 1 | 175.0 | BRICK | EXPERIMENTAL | Runs camera passthrough plus the AR overlay, outputs side-by-side 3840x1080 over HDMI, and does local AI. A Pi 5 4 GB also works. | https://www.raspberrypi.com/products/raspberry-pi-5/ | NEW (Vision Pro-style pocket brick)
Brick power | USB-C power bank, 2 outputs, at least 5V/3A |  | 1 | 35.0 | BRICK | PROTOTYPE-READY | Port 1 powers the Pi. Port 2 powers the glasses 5 V through the USB lead (keeps load off the Pi's 600 mA USB limit). |  | NEW
Brick storage | microSD 64 GB A2 |  | 1 | 10.0 | BRICK | PROTOTYPE-READY | Raspberry Pi OS 64-bit + brick/ software. |  | kept
Phone | Any phone with Chrome (Android) for the Web Bluetooth controls |  | 0 | 0 | PHONE | PROTOTYPE-READY | Designs, brightness, text and status via the web app's Glasses tab. Heavy AI can run on the phone or the brick. |  | NEW

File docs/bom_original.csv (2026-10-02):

subsystem | item | part_or_example | qty | approx_unit_usd | tier | engineering_notes | source_url
Core MCU | Seeed Studio XIAO ESP32-S3 | XIAO ESP32-S3 | 1 | 7.49 | CORE | BLE/Wi-Fi MCU; use non-Sense version to avoid an unwanted camera. | https://wiki.seeedstudio.com/xiao_esp32s3_getting_started/
Depth sensing | SparkFun Qwiic Mini ToF Imager | VL53L5CX / SEN-19013 | 1 | 25.95 | CORE | 64-zone 8x8 ToF; bridge-mounted; no image camera. | https://www.sparkfun.com/sparkfun-qwiic-mini-tof-imager-vl53l5cx.html
Motion | ICM-42688-P breakout | ICM-42688-P | 1 | 15.0 | CORE | 6-axis IMU; any compact 3.3V I2C breakout is acceptable. | https://www.invensense.tdk.com/en-us/products/6-axis/icm-42688-p
Pressure | BMP390 breakout | BMP390 | 1 | 10.99 | CORE | Pressure trend for flight-mode suggestion; not sole aircraft detector. | https://www.bosch-sensortec.com/en/products/environmental-sensors/pressure-sensors/bmp390
Ambient | SHT40 breakout | SHT40 | 1 | 5.95 | CORE | Ambient temperature/humidity; mount in a ventilated outer pod away from skin. | https://www.adafruit.com/product/4885
Microphone | I2S MEMS microphone breakout | SPH0645LM4H | 1 | 6.95 | CORE | Powered only by physical PTT switch. | https://www.adafruit.com/product/3421
Audio amp | I2S Class-D amplifier | MAX98357A | 2 | 5.95 | CORE | One amp for bone path, one for outward speakers; independent SD control. | https://www.adafruit.com/product/3006
Bone audio | 8 ohm 1 W bone-conduction transducer | 8R 1W | 2 | 8.0 | CORE | Mount near mastoid via compliant TPU carrier; do not clamp hard. | https://www.adafruit.com/product/1674
Open audio | 8 ohm 1–2 W micro speaker | 8R 1-2W | 2 | 4.0 | CORE | Directional/open-ear outward audio; keep volume conservative. | https://www.adafruit.com/category/271
Charging | USB-C Li-ion/LiPo charger with load sharing | BQ24074 breakout | 1 | 14.95 | CORE | External charger preferred; set charge current to match the pack; add NTC. | https://learn.adafruit.com/adafruit-bq24074-universal-usb-dc-solar-charger-breakout
Battery | Protected 1S LiPo 1200 mAh | 3.7V 1200mAh | 1 | 9.95 | CORE | Rear/side pod; use a protected pack from a reputable supplier. | https://www.adafruit.com/category/574
5V regulator | 5V boost converter, >=1 A core mode | TPS61023-class | 1 | 6.0 | CORE | Feeds 5V system/audio rail; media pod uses its own higher-current supply. | https://www.adafruit.com/category/578
Battery thermal | 10k NTC thermistor | 10k NTC | 1 | 1.0 | CORE | Bond to pouch cell; use charger TS/thermistor input when supported. | https://www.adafruit.com/category/66
Privacy control | DPST momentary pushbutton | PTT switch | 1 | 4.0 | CORE | Pole A switches microphone rail; Pole B is MCU PTT sense. | https://www.digikey.com/en/products/filter/pushbutton-switches/199
Power control | SPST/DPST slide switch | MAIN POWER | 1 | 2.0 | CORE | Physical on/off between charger load output and system regulator. | https://www.digikey.com/en/products/filter/slide-switches/213
Privacy indicator | Red LED + 1k resistor | MIC ON | 1 | 0.25 | CORE | Wired directly to switched microphone rail.
Harness | 28–32 AWG silicone wire + JST-SH/Qwiic pigtails | Harness | 1 | 10.0 | CORE | Use strain relief at both hinges.
Fasteners | M2 x 5/6 mm screws + M2 heat-set inserts | M2 | 1 | 8.0 | CORE | Serviceable covers and pods.
Soft grip | 95A TPU + 1–2 mm silicone/memory foam tape | Ear grip | 1 | 8.0 | CORE | Printed TPU shell with replaceable inward foam strip.
Combiner optics | Optical-grade partial reflector / beam splitter | ~30R/70T | 2 | 25.0 | HUD | Do not use printed transparent plastic for final optics.
HUD display | Compact micro-OLED + collimator/driver | 640x400-class | 1 | 99.0 | HUD | Start monocular; controller compatibility must be confirmed before purchase.
HUD optics | Collimating/aspheric lens + adjustable holder | 20–25 mm class | 1 | 20.0 | HUD | Tune focal position and eyebox experimentally.
Media compute | Raspberry Pi Zero 2 W | SC0510 | 1 | 14.99 | MEDIA | Optional H.264 media renderer; core MCU remains safety authority. | https://www.raspberrypi.com/products/raspberry-pi-zero-2-w/
Media display | High-resolution micro-OLED + HDMI/MIPI controller | 720p/1080p class | 1 | 150.0 | MEDIA | Prototype one eye before buying the second display.
Media power | Protected 1S LiPo 2000–3000 mAh + 5V >=2A regulator | rear media pack | 1 | 25.0 | MEDIA | Separate rear pod improves thermal balance; charge with matched safe charger.
Media storage | microSD 32 GB | A1/A2 card | 1 | 7.0 | MEDIA | OS and cached media/translation assets for Pi-based mode.

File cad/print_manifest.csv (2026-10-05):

part | material | tier | orientation | supports | layer_mm | walls | infill | plate_3mf | notes | bbox_mm | solid_mass_g | fits_A1_mini
tolerance_coupon | PETG | print FIRST | flat | none | 0.16 | 4 | 30% gyroid | plate_0 | Tune the insert hole, tube fits (temple 4.05 glue / 4.35 run, visor 4.2 friction) and the magnet pocket, then rebuild. | 82.0x30.0x6.0 | 16.7 | True
frame | PETG | GLASSES | front face down | none | 0.16 | 4 | 30% gyroid | plate_1 | Ream the temple knuckles to 4.35 and the visor knuckles to 4.2 (friction holds the visor up). Press the 6x3 magnet in. | 129.0x50.8x12.8 | 12.6 | True
temple_left | PETG | GLASSES | head face down | none | 0.16 | 4 | 30% gyroid | plate_1 | Drill the knuckle to 4.05 and glue the tube. The cell drops into the earpiece bay from the head side. | 52.6x134.7x6.8 | 7.8 | True
temple_right | PETG | GLASSES | head face down | none | 0.16 | 4 | 30% gyroid | plate_1 | Same as the left temple. | 52.6x134.7x6.8 | 7.8 | True
visor_shell | PETG black | GLASSES | front face down | none | 0.16 | 4 | 25% gyroid | plate_2 | Fit 4 M2 inserts in the back bosses. Visor knuckles: drill to 4.05 and glue the tubes. | 113.0x47.0x42.6 | 30.4 | True
visor_back | PETG black | GLASSES | eye side down | none | 0.16 | 3 | 25% gyroid | plate_2 | The eyepiece sleeves hold the optics with crush ribs. Fits with 4 x M2x6. | 113.0x47.0x24.0 | 14.5 | True
ear_grip_left | TPU 95A | GLASSES | entry end down | none | 0.20 | 3 | 20% gyroid | plate_3 | Slide over the earpiece to close the battery bay. Feed TPU from the external spool. | 9.2x15.6x54.8 | 3.6 | True
ear_grip_right | TPU 95A | GLASSES | entry end down | none | 0.20 | 3 | 20% gyroid | plate_3 | Same as the left grip. | 9.2x15.6x54.8 | 3.6 | True

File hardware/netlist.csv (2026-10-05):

net | ref | module | pin | part | location | wire | net_description
BAT+ | BT1 | Cell LEFT | + | Protected 1S LiPo 501040 200 mAh | Left earpiece | 28 AWG red | Both cells in parallel
BAT+ | BT2 | Cell RIGHT | + | Protected 1S LiPo 501040 200 mAh | Right earpiece | 28 AWG red | Both cells in parallel
BAT+ | SW1 | Main power | COM | Wurth 452403012014 DPDT slide | Visor crest top | 28 AWG red | Both cells in parallel
BAT_SW | SW1 | Main power | throw A | Wurth 452403012014 DPDT slide | Visor crest top | local | Switched battery
BAT_SW | U1 | XIAO ESP32-S3 | BAT+ pad | Seeed XIAO ESP32-S3 (non-Sense) | Visor bridge, behind camera | local | Switched battery
BAT_SW | R2 | 100k top | 1 | 100k 1/8 W | Visor bridge | local | Switched battery
VBAT_DIV | R2 | 100k top | 2 | 100k 1/8 W | Visor bridge | local | Half battery voltage to ADC
VBAT_DIV | R3 | 100k bottom | 1 | 100k 1/8 W | Visor bridge | local | Half battery voltage to ADC
VBAT_DIV | U1 | XIAO ESP32-S3 | D3 (A2) | Seeed XIAO ESP32-S3 (non-Sense) | Visor bridge, behind camera | local | Half battery voltage to ADC
VBUS_5V | J1 | Brick cable | USB VBUS | micro-HDMI->HDMI + USB 4-core, braided | Enters visor crest, left side | USB red | 5 V from the brick / power bank
VBUS_5V | D2 | 1N5817 | anode | 1N5817 Schottky | Visor crest | USB red | 5 V from the brick / power bank
VBUS_5V | SW2 | Camera kill | COM | Wurth 452403012014 DPDT slide | Visor crest top | USB red | 5 V from the brick / power bank
VBUS_5V | U7 | Micro-OLED board | 5V in | Dual 0.71in micro-OLED HDMI driver | Visor crest bay | USB red | 5 V from the brick / power bank
XIAO_5V | D2 | 1N5817 | cathode (band) | 1N5817 Schottky | Visor crest | local | XIAO 5V pin, also charges the cells
XIAO_5V | U1 | XIAO ESP32-S3 | 5V | Seeed XIAO ESP32-S3 (non-Sense) | Visor bridge, behind camera | local | XIAO 5V pin, also charges the cells
CAM_5V | SW2 | Camera kill | throw A | Wurth 452403012014 DPDT slide | Visor crest top | local | Camera power, ONLY with SW2 on
CAM_5V | U2 | Camera | 5V (USB VBUS) | Arducam IMX708 UVC 102 deg | Visor centre bridge, front | local | Camera power, ONLY with SW2 on
CAM_5V | R1 | 1k | 1 | 1k 1/8 W | Visor crest | local | Camera power, ONLY with SW2 on
LED_A | R1 | 1k | 2 | 1k 1/8 W | Visor crest | local | LED current limit
LED_A | D1 | CAMERA LIVE LED | anode (long leg) | 3 mm red LED | Visor front, beside camera | local | LED current limit
GND | BT1 | Cell LEFT | - | Protected 1S LiPo 501040 200 mAh | Left earpiece | 28 AWG black | Common ground
GND | BT2 | Cell RIGHT | - | Protected 1S LiPo 501040 200 mAh | Right earpiece | 28 AWG black | Common ground
GND | J1 | Brick cable | USB GND / HDMI shell | micro-HDMI->HDMI + USB 4-core, braided | Enters visor crest, left side | 28 AWG black | Common ground
GND | U1 | XIAO ESP32-S3 | GND + BAT- pad | Seeed XIAO ESP32-S3 (non-Sense) | Visor bridge, behind camera | 28 AWG black | Common ground
GND | R3 | 100k bottom | 2 | 100k 1/8 W | Visor bridge | 28 AWG black | Common ground
GND | D1 | CAMERA LIVE LED | cathode | 3 mm red LED | Visor front, beside camera | 28 AWG black | Common ground
GND | U2 | Camera | GND | Arducam IMX708 UVC 102 deg | Visor centre bridge, front | 28 AWG black | Common ground
GND | U3 | IMU | GND | Adafruit 4438 LSM6DSOX | Visor bridge | 28 AWG black | Common ground
GND | U4 | Hall switch | GND | TI DRV5032FA on SOT-23 adapter | Back of visor bridge, faces brow magnet | 28 AWG black | Common ground
GND | U5 | LCD LEFT | GND | Waveshare 1.69in 240x280 ST7789V2 | Left pod, front | 28 AWG black | Common ground
GND | U6 | LCD RIGHT | GND | Waveshare 1.69in 240x280 ST7789V2 | Right pod, front | 28 AWG black | Common ground
GND | U7 | Micro-OLED board | GND | Dual 0.71in micro-OLED HDMI driver | Visor crest bay | 28 AWG black | Common ground
GND | SW3 | Action button | pin 2 | Omron B3F-1000 6x6 tact | Visor crest top flexure | 28 AWG black | Common ground
3V3 | U1 | XIAO ESP32-S3 | 3V3 | Seeed XIAO ESP32-S3 (non-Sense) | Visor bridge, behind camera | local | Logic supply from the XIAO
3V3 | U3 | IMU | VIN (Qwiic) | Adafruit 4438 LSM6DSOX | Visor bridge | local | Logic supply from the XIAO
3V3 | U4 | Hall switch | VCC | TI DRV5032FA on SOT-23 adapter | Back of visor bridge, faces brow magnet | local | Logic supply from the XIAO
3V3 | U5 | LCD LEFT | VCC + RST | Waveshare 1.69in 240x280 ST7789V2 | Left pod, front | local | Logic supply from the XIAO
3V3 | U6 | LCD RIGHT | VCC + RST | Waveshare 1.69in 240x280 ST7789V2 | Right pod, front | local | Logic supply from the XIAO
USB_D+ | J1 | Brick cable | USB D+ | micro-HDMI->HDMI + USB 4-core, braided | Enters visor crest, left side | USB green | Camera USB data to the brick
USB_D+ | U2 | Camera | D+ | Arducam IMX708 UVC 102 deg | Visor centre bridge, front | USB green | Camera USB data to the brick
USB_D- | J1 | Brick cable | USB D- | micro-HDMI->HDMI + USB 4-core, braided | Enters visor crest, left side | USB white
USB_D- | U2 | Camera | D- | Arducam IMX708 UVC 102 deg | Visor centre bridge, front | USB white
HDMI | J1 | Brick cable | HDMI | micro-HDMI->HDMI + USB 4-core, braided | Enters visor crest, left side | HDMI cable | Side-by-side 3840x1080 video
HDMI | U7 | Micro-OLED board | HDMI in | Dual 0.71in micro-OLED HDMI driver | Visor crest bay | HDMI cable | Side-by-side 3840x1080 video
SPI_SCK | U1 | XIAO ESP32-S3 | D8 | Seeed XIAO ESP32-S3 (non-Sense) | Visor bridge, behind camera | local | LCD clock (shared)
SPI_SCK | U5 | LCD LEFT | CLK | Waveshare 1.69in 240x280 ST7789V2 | Left pod, front | local | LCD clock (shared)
SPI_SCK | U6 | LCD RIGHT | CLK | Waveshare 1.69in 240x280 ST7789V2 | Right pod, front | local | LCD clock (shared)
SPI_MOSI | U1 | XIAO ESP32-S3 | D10 | Seeed XIAO ESP32-S3 (non-Sense) | Visor bridge, behind camera | local | LCD data (shared)
SPI_MOSI | U5 | LCD LEFT | DIN | Waveshare 1.69in 240x280 ST7789V2 | Left pod, front | local | LCD data (shared)
SPI_MOSI | U6 | LCD RIGHT | DIN | Waveshare 1.69in 240x280 ST7789V2 | Right pod, front | local | LCD data (shared)
LCD_DC | U1 | XIAO ESP32-S3 | D2 | Seeed XIAO ESP32-S3 (non-Sense) | Visor bridge, behind camera | local | Data / command (shared)
LCD_DC | U5 | LCD LEFT | DC | Waveshare 1.69in 240x280 ST7789V2 | Left pod, front | local | Data / command (shared)
LCD_DC | U6 | LCD RIGHT | DC | Waveshare 1.69in 240x280 ST7789V2 | Right pod, front | local | Data / command (shared)
CS_L | U1 | XIAO ESP32-S3 | D0 | Seeed XIAO ESP32-S3 (non-Sense) | Visor bridge, behind camera | local | Select left LCD
CS_L | U5 | LCD LEFT | CS | Waveshare 1.69in 240x280 ST7789V2 | Left pod, front | local | Select left LCD
CS_R | U1 | XIAO ESP32-S3 | D1 | Seeed XIAO ESP32-S3 (non-Sense) | Visor bridge, behind camera | local | Select right LCD
CS_R | U6 | LCD RIGHT | CS | Waveshare 1.69in 240x280 ST7789V2 | Right pod, front | local | Select right LCD
LCD_BL | U1 | XIAO ESP32-S3 | D6 | Seeed XIAO ESP32-S3 (non-Sense) | Visor bridge, behind camera | local | Backlight PWM (shared)
LCD_BL | U5 | LCD LEFT | BL | Waveshare 1.69in 240x280 ST7789V2 | Left pod, front | local | Backlight PWM (shared)
LCD_BL | U6 | LCD RIGHT | BL | Waveshare 1.69in 240x280 ST7789V2 | Right pod, front | local | Backlight PWM (shared)
SDA | U1 | XIAO ESP32-S3 | D4 | Seeed XIAO ESP32-S3 (non-Sense) | Visor bridge, behind camera | Qwiic blue | I2C data
SDA | U3 | IMU | SDA (Qwiic) | Adafruit 4438 LSM6DSOX | Visor bridge | Qwiic blue | I2C data
SCL | U1 | XIAO ESP32-S3 | D5 | Seeed XIAO ESP32-S3 (non-Sense) | Visor bridge, behind camera | Qwiic yellow | I2C clock
SCL | U3 | IMU | SCL (Qwiic) | Adafruit 4438 LSM6DSOX | Visor bridge | Qwiic yellow | I2C clock
HALL | U4 | Hall switch | OUT | TI DRV5032FA on SOT-23 adapter | Back of visor bridge, faces brow magnet | local | Visor down = LOW
HALL | U1 | XIAO ESP32-S3 | D7 | Seeed XIAO ESP32-S3 (non-Sense) | Visor bridge, behind camera | local | Visor down = LOW
BUTTON | SW3 | Action button | pin 1 | Omron B3F-1000 6x6 tact | Visor crest top flexure | local | Action button (pull-up)
BUTTON | U1 | XIAO ESP32-S3 | D9 | Seeed XIAO ESP32-S3 (non-Sense) | Visor bridge, behind camera | local | Action button (pull-up)
OLED_FPC | U7 | Micro-OLED board | FPC L / FPC R | Dual 0.71in micro-OLED HDMI driver | Visor crest bay | panel flex | Panel flex cables
NC / prep | U5 | LCD LEFT | RST | Waveshare 1.69in 240x280 ST7789V2 | Left pod, front |  | tie to 3V3 (the firmware sends a software reset)
NC / prep | U6 | LCD RIGHT | RST | Waveshare 1.69in 240x280 ST7789V2 | Right pod, front |  | tie to 3V3
NC / prep | U1 | XIAO ESP32-S3 | D3 | Seeed XIAO ESP32-S3 (non-Sense) | Visor bridge, behind camera |  | ADC: VBAT/2
NC / prep | U7 | Micro-OLED board | 5V in | Dual 0.71in micro-OLED HDMI driver | Visor crest bay |  | power the HDMI board from VBUS, never from the XIAO 3V3
NC / prep | BT1 | Cell LEFT | before joining | Protected 1S LiPo 501040 200 mAh | Left earpiece |  | charge both cells to 4.2 V separately, then wire them in parallel

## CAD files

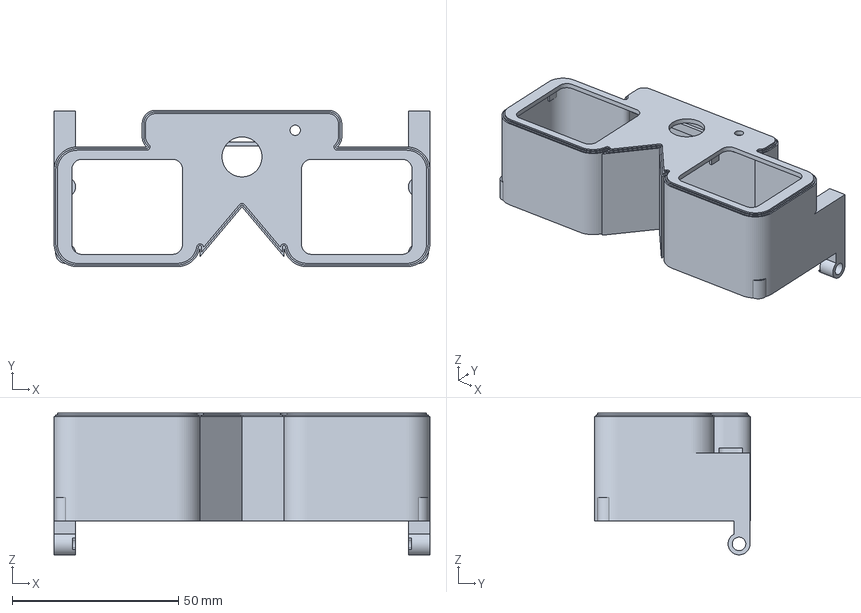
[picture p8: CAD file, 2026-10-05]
cad/3mf/visor_shell.3mf
113.0 x 47.0 x 42.6 mm

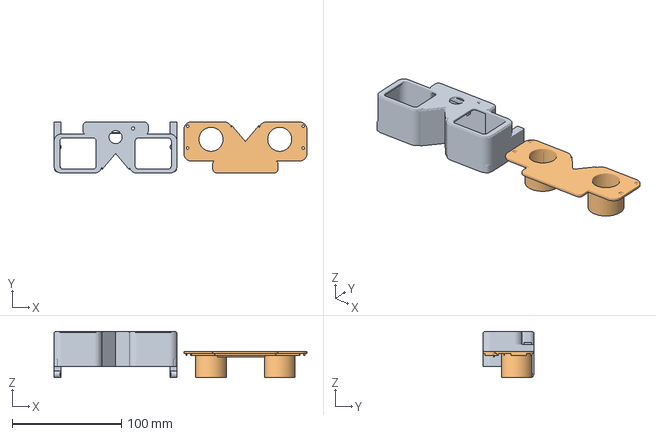
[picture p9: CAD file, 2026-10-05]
cad/plates/plate_2_visor_petg.3mf
232.0 x 47.0 x 42.6 mm
visor_shell
visor_back

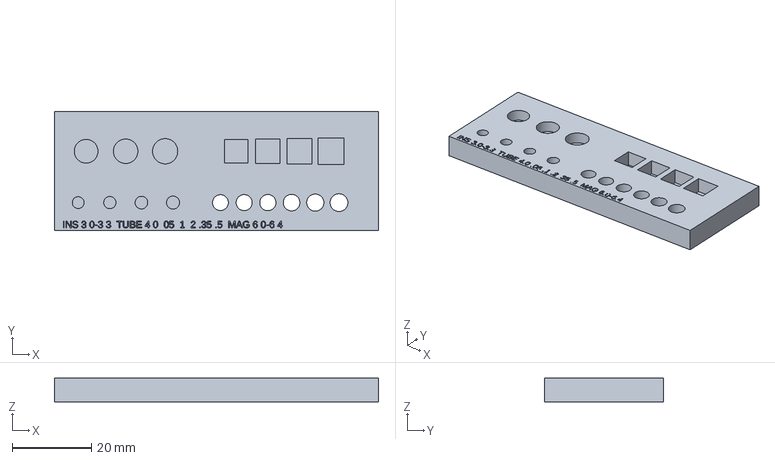
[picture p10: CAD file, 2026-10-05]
cad/3mf/tolerance_coupon.3mf
82.0 x 30.0 x 6.00 mm

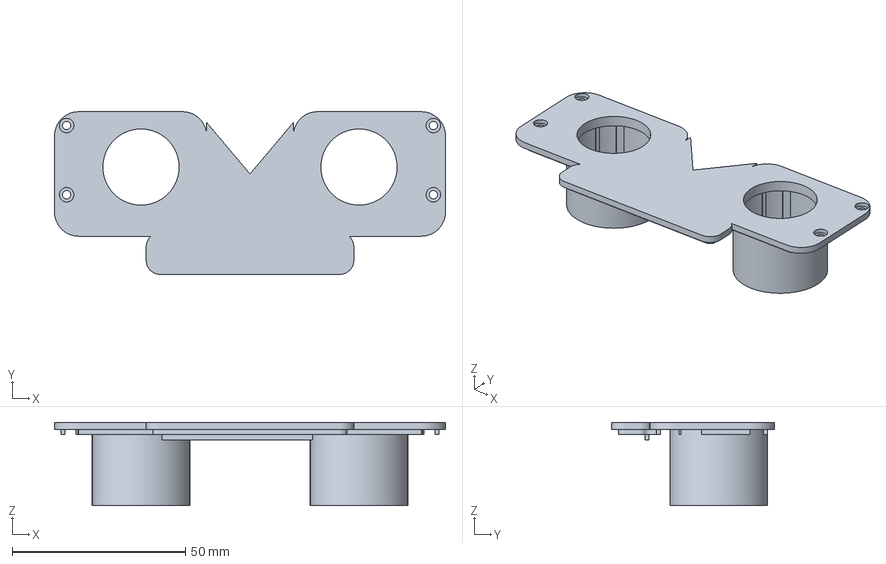
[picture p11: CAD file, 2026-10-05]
cad/3mf/visor_back.3mf
113.0 x 47.0 x 24.0 mm

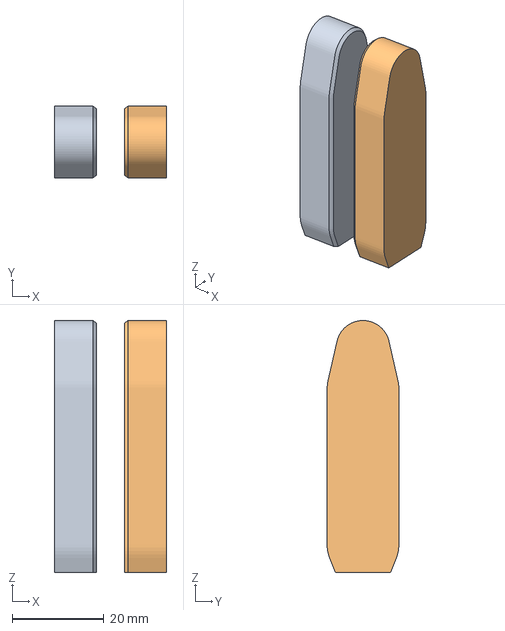
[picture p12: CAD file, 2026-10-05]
cad/plates/plate_3_tpu_grips.3mf
24.4 x 15.6 x 54.8 mm
ear_grip_left
ear_grip_right

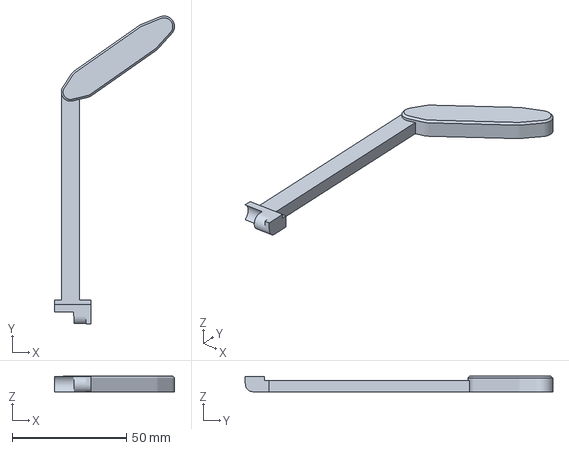
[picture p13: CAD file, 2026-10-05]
cad/3mf/temple_left.3mf
52.6 x 134.7 x 6.80 mm

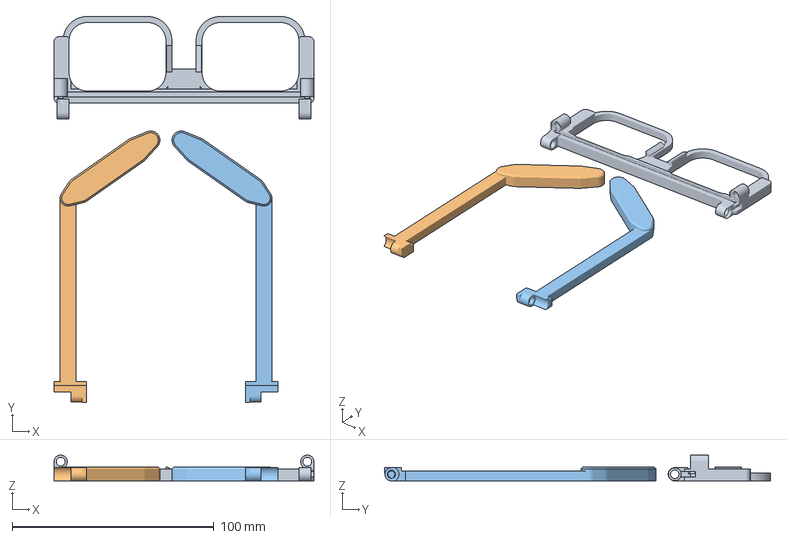
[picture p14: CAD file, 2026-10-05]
cad/plates/plate_1_frame_temples_petg.3mf
129.0 x 191.5 x 12.8 mm
frame
temple_left
temple_right

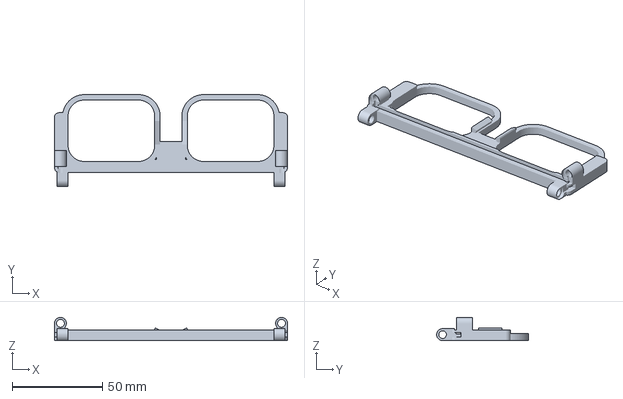
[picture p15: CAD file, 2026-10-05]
cad/3mf/frame.3mf
129.0 x 50.8 x 12.8 mm

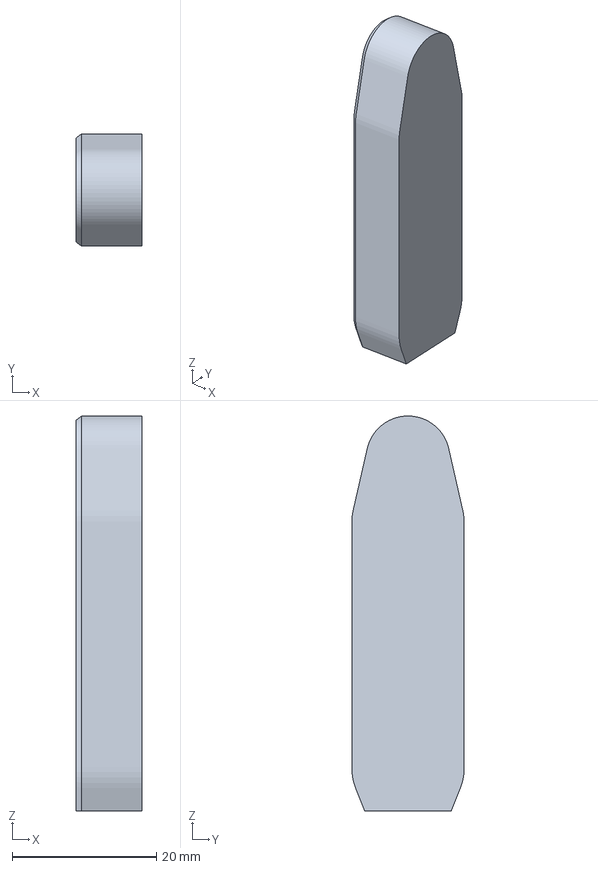
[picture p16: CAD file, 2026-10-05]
cad/3mf/ear_grip_right.3mf
9.20 x 15.6 x 54.8 mm

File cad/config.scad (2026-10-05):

// ============================================================================
// Adaptive Smart Glasses v0.2 — config.scad (ALL tunable dimensions)
// Camera-passthrough glasses: flip-up display visor + slim frame + battery earpieces.
// Assembly coordinates (wearer's view): +X = wearer's LEFT, +Y = toward the head,
// +Z = up. Frame front face is Y = 0, pupils sit at Z = 0.
// [MEASURE] = estimate or vendor drawing not yet confirmed: measure your part, edit, rebuild.
// ============================================================================

// ---------- print tolerances (tune with tolerance_coupon) ----------
tol            = 0.30;
fn_fine        = 64;
fn_coarse      = 32;

// ---------- head fit ----------
ipd            = 63;     // pupil distance: centres both eyepieces
head_width     = 148;    // sets temple splay
ear_y          = 98;     // hinge axis -> ear bend
ear_droop      = 55;     // earpiece angle below horizontal
earpiece_len   = 50;     // bend -> tip (holds the battery)
eye_relief     = 17;     // cornea -> eyepiece exit (sets visor_rear_y)   [MEASURE optics]

// ---------- slim front frame (stays on the face; visor hinges on it) ----------
lens_w = 48; lens_h = 34; lens_r = 9; dbl = 18; rim = 3.0;
frame_depth    = 4.0;
brow_z0        = lens_h/2 - 1;
brow_z1        = 23;
brow_depth     = 6.0;
endpiece_w     = 4.5;
endpiece_z0    = -10;
magnet         = [6.2, 3.2];   // Ø x depth: 6x3 mm N52 disc, brow centre (hall sensor target)

// ---------- temple hinge (hollow brass tube, wires inside) ----------
tz             = 12;
knuckle_r      = 3.3;
tube_hole_glue = 4.05;
tube_hole_run  = 4.35;
flare_d        = 6.4;
tk_z           = [-6.5, -1.5];
fk_z           = [-1.2, 7.8];
hinge_gap      = 0.25;
bar_in         = -knuckle_r;   // temple head-side face (flat = print face)
bar_t          = 5.0;

// ---------- earpiece battery (one protected cell per side) ----------
cell           = [40, 10, 5.0];   // L x W x T: 501040 200 mAh (or LP401235 4x12x36) [MEASURE]
cell_s0        = 4;               // bay starts this far past the ear bend

// ---------- visor (flip-up display unit) ----------
visor_rear_y   = -1.6;            // eyepiece-side face
visor_depth    = 34.4;            // rear -> front
pod_cx         = 34.5;            // pod centre X (LCD centre)
pod_w          = 44;  pod_z = [-16, 20];  pod_r = 7;
bridge_hw      = 12.6;            // centre bridge half width (camera board 24 wide)
crest_hw       = 30;  crest_z = [19, 31];  // top bay: display driver board + controls
nose_apex_z    = 2;  nose_base_hw = 16;    // nose notch (apex height, half width at bottom)
wall           = 1.6;
visor_axis     = [3.3, 27.5];     // visor hinge axis (Y, Z) along X, sits on the brow top (frame prints front-down)
visor_knuckle_x = [50, 56.5];     // visor knuckle span (|X|)
frame_vknuckle_x = [57, 63];      // frame knuckle span (|X|)
visor_tube_run = 4.2;             // frame-side bore: snug = friction holds the visor up [coupon]
visor_up_deg   = 100;

// ---------- visor modules ----------
lcd            = [39.0, 31.5, 4.5];   // Waveshare 1.69" 240x280, landscape (W x H x T) [MEASURE T]
lcd_active     = [32.63, 27.97];
cam_board      = [24, 25, 1.6];       // Arducam IMX708 UVC 102 deg
cam_lens_d     = 12;                  // front aperture for the lens holder        [MEASURE]
cam_z          = 17;                  // camera board centre height
oled_panel     = [24.24, 15.62, 1.54];// Sony ECX335S 0.71" 1920x1080 (FPC exits top)
eyepiece_d     = 26;  eyepiece_len = 22;  // OPE07-10X prism eyepiece            [MEASURE]
hdmi_board     = [45, 28, 7];         // dual micro-OLED HDMI driver board           [MEASURE]
xiao           = [21, 17.5, 4.2];
imu            = [25.4, 17.78, 4.6];
sw_slide       = [7.65, 5.5, 4.5];    // Wurth 452403012014 DPDT body (x2)           [MEASURE]
ptt            = [6.2, 6.2, 4.3];     // 6x6 tact (action button)
cable_slot     = [11, 7];             // HDMI + USB bundle entry (crest left side)

// ---------- fasteners ----------
insert_hole_d  = 3.1;  insert_depth = 5.5;  m2_clear = 2.4;  m2_head_d = 4.2;  m2_tap = 1.75;

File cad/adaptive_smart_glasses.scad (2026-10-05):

// ============================================================================
// Adaptive Smart Glasses v0.2 — camera-passthrough glasses (parametric, P1S-printable)
//
//   openscad -D 'part="visor_shell"' -o visor_shell.stl adaptive_smart_glasses.scad
//   part = assembly | assembly_up | frame | temple_left | temple_right | ear_grip_left
//          | ear_grip_right | visor_shell | visor_back | tolerance_coupon
//   part="asm" + which="<part>"  -> that part in assembly position (web viewer)
//
// Layout: slim FRAME on the face (nose pads, temples, hinges). Batteries sit in the
// EARPIECES (counterweight). A flip-up VISOR hinges on the brow and carries everything
// else: 2 inward micro-OLED eyepieces, 2 outward 1.69" design screens, centre camera,
// XIAO ESP32-S3, IMU, display driver board, power / camera-privacy switches, action button.
// Status: PROTOTYPE-READY mechanics (fit-check first); optics + passthrough EXPERIMENTAL.
// ============================================================================
include <config.scad>

part  = "assembly";
which = "frame";
up_deg = 0;      // visor angle for part="asm" (0 = down, visor_up_deg = up)
$fn   = fn_coarse;

// ---------------- derived ----------------
lens_cx  = dbl/2 + lens_w/2;
half_w   = dbl/2 + lens_w + rim + endpiece_w;
axis_x   = half_w - knuckle_r;
axis_y   = brow_depth + knuckle_r + hinge_gap;
splay    = atan((head_width/2 + 1 - (axis_x + bar_in)) / ear_y);
ear_dir  = [cos(ear_droop), -sin(ear_droop)];
ear_B    = [ear_y, 0];
ear_T    = ear_B + earpiece_len*ear_dir;
function ear_pt(s) = ear_B + s*ear_dir;
vf       = visor_rear_y - visor_depth;   // visor front face (Y)
sb       = visor_rear_y - 2;             // shell back opening (back plate is 2 mm)
pod_mz   = (pod_z[0] + pod_z[1]) / 2;
VA       = [0, visor_axis[0], visor_axis[1]];   // visor axis point (X ignored)

// ---------------- helpers ----------------
module rr2(w, h, r) { offset(r=r) square([max(w-2*r,0.01), max(h-2*r,0.01)], center=true); }
module yz(x0, x1) { multmatrix([[0,0,1,0],[1,0,0,0],[0,1,0,0],[0,0,0,1]]) translate([0,0,x0]) linear_extrude(x1-x0) children(); }
module xz(y0, y1) { translate([0,y1,0]) rotate([90,0,0]) linear_extrude(y1-y0) children(); }
module cubeb(a, b) { translate(a) cube(b - a); }
module cyl_y(d, y0, y1) { translate([0,y0,0]) rotate([-90,0,0]) cylinder(d=d, h=y1-y0, $fn=fn_fine); }
module cyl_x(d, x0, x1) { translate([x0,0,0]) rotate([0,90,0]) cylinder(d=d, h=x1-x0, $fn=fn_fine); }

// ============================================================================
// FRAME — slim carrier (print: front face down). Visor knuckles sit on the brow top.
// ============================================================================
module lens2d() { rr2(lens_w, lens_h, lens_r); }
module frame_rims2d() {
    for (s=[-1,1]) translate([s*lens_cx,0]) offset(r=rim) lens2d();
    translate([-8, 6]) square([16, brow_z0 - 5]);
}
module frame_brow2d() {
    offset(r=2.5) offset(delta=-2.5) union() {
        translate([-half_w, brow_z0]) square([2*half_w, brow_z1-brow_z0]);
        for (s=[-1,1]) translate([s>0 ? half_w-endpiece_w-rim-1 : -half_w, endpiece_z0]) square([endpiece_w+rim+1, brow_z1-endpiece_z0]);
    }
}
module temple_lug_local() {
    hull() {
        cubeb([-1.5, -(axis_y-brow_depth)-0.5, fk_z[0]], [knuckle_r, -(axis_y-brow_depth), fk_z[1]]);
        translate([0,0,fk_z[0]]) cylinder(r=knuckle_r, h=fk_z[1]-fk_z[0], $fn=fn_fine);
    }
}
module temple_lug_cuts_local() {
    translate([0,0,fk_z[0]-1]) cylinder(d=tube_hole_run, h=20, $fn=fn_fine);
    translate([0,0,fk_z[1]-1.5]) cylinder(d=flare_d, h=5, $fn=fn_fine);
    cubeb([-1.25, -6, fk_z[1]-2.5], [1.25, 0, fk_z[1]+1]);
}
module frame_body() {
    xz(0, frame_depth) frame_rims2d();
    xz(0, brow_depth)  frame_brow2d();
    for (s=[-1,1]) translate([s*8.0, frame_depth+1.0, 1]) rotate([0,0,s*25]) cube([3, 3, 13], center=true);  // nose-pad lands
    for (s=[-1,1]) translate([s*axis_x, axis_y, tz]) mirror([s<0?1:0,0,0]) temple_lug_local();
    for (s=[-1,1]) mirror([s<0?1:0,0,0]) {                                      // visor knuckles on brow top
        translate([frame_vknuckle_x[0], visor_axis[0], visor_axis[1]]) cyl_x(2*knuckle_r, 0, frame_vknuckle_x[1]-frame_vknuckle_x[0]);
        cubeb([frame_vknuckle_x[0], max(0, visor_axis[0]-knuckle_r), brow_z1-2], [frame_vknuckle_x[1], visor_axis[0]+knuckle_r, visor_axis[1]]);
    }
}
module frame_cuts() {
    for (s=[-1,1]) translate([s*lens_cx,0,0]) xz(-1, 30) lens2d();
    for (s=[-1,1]) translate([s*axis_x, axis_y, tz]) mirror([s<0?1:0,0,0]) temple_lug_cuts_local();
    for (s=[-1,1]) mirror([s<0?1:0,0,0]) {
        translate([frame_vknuckle_x[0]-1, visor_axis[0], visor_axis[1]]) cyl_x(visor_tube_run, 0, 20);   // visor tube (turns, snug)
        translate([frame_vknuckle_x[1]-1.5, visor_axis[0], visor_axis[1]]) cyl_x(flare_d, 0, 5);         // flare / washer seat
        // wire path: temple knuckle top -> endpiece -> visor knuckle outer end
        cubeb([axis_x-1.25, 2.0, tz+fk_z[1]-2.5], [axis_x+1.25, axis_y, tz+fk_z[1]]);
        cubeb([frame_vknuckle_x[1]-0.8, 2.0, tz+fk_z[1]-2.5], [frame_vknuckle_x[1]+1.5, 4.6, visor_axis[1]]);
        cubeb([axis_x-1.25, 2.0, tz+fk_z[1]-2.5], [frame_vknuckle_x[1]+1.5, 4.6, tz+fk_z[1]]);
    }
    cubeb([-axis_x+1, 3.6, brow_z0+1.5], [axis_x-1, brow_depth+1, brow_z0+4.0]);     // cross-brow groove (right cell)
    translate([0, -0.01, brow_z0+3.8]) cyl_y(magnet[0], 0, magnet[1]);                // hall-sensor magnet
}
module frame() { difference() { frame_body(); frame_cuts(); } }

// ============================================================================
// TEMPLES (local: origin on hinge axis at z = tz, +y back, +x outward, head face x = bar_in)
// The earpiece holds one protected cell, covered by the TPU grip.
// ============================================================================
module bar2d() {
    translate([0,-9]) square([7, 16]);
    hull() { translate([8,0]) circle(r=4); translate(ear_B) circle(r=4); }
}
module earpiece2d(g=0) {
    offset(delta=g) hull() {
        translate(ear_B) circle(r=4);
        translate(ear_pt(cell_s0+3)) circle(r=cell[1]/2+1.6);
        translate(ear_pt(cell_s0+cell[0]-3)) circle(r=cell[1]/2+1.6);
        translate(ear_T) circle(r=4.6);
    }
}
ear_t1 = bar_in + cell[2] + 0.4 + 1.4;   // earpiece outer face
module ear_frame() { translate([0, ear_B[0], ear_B[1]]) rotate([-ear_droop,0,0]) children(); }
module temple_body() {
    yz(bar_in, bar_in+bar_t) bar2d();
    yz(bar_in, knuckle_r) translate([0,-9]) square([5, 16]);
    hull() { yz(bar_in, ear_t1-0.8) earpiece2d(); yz(bar_in, ear_t1) earpiece2d(-0.8); }
}
module temple_hinge_part() {
    translate([0,0,-9]) cylinder(r=knuckle_r, h=tk_z[1]+9, $fn=fn_fine);
    cubeb([0.3, -(axis_y-brow_depth)+0.1, -9], [knuckle_r, 0, -6.8]);       // open stop
}
module temple_cuts() {
    ear_frame() cubeb([bar_in-0.1, cell_s0, -(cell[1]/2+0.2)], [bar_in+cell[2]+0.4, cell_s0+cell[0]+0.5, cell[1]/2+0.2]);  // cell bay
    yz(bar_in-0.1, bar_in+1.4) {                                             // wire groove, head side
        hull() { translate(ear_pt(cell_s0+1)) circle(d=1.8, $fn=12); translate(ear_B+[0,-1]) circle(d=1.8, $fn=12); }
        hull() { translate(ear_B+[0,-1]) circle(d=1.8, $fn=12); translate([5,-1]) circle(d=1.8, $fn=12); }
        hull() { translate([5,-1]) circle(d=1.8, $fn=12); translate([5,-7.2]) circle(d=1.8, $fn=12); }
    }
    cubeb([bar_in-0.1, -0.5, -8.6], [bar_in+2.0, 5.9, -6.6]);
}
module temple_local(side, splayed=true) {
    difference() {
        union() {
            rotate([0,0, splayed ? -splay : 0]) difference() {
                temple_body();
                temple_cuts();
                translate([0,0,fk_z[0]-hinge_gap]) cylinder(r=knuckle_r+hinge_gap+0.2, h=20, $fn=fn_fine);
                translate([-10,-10,fk_z[0]-hinge_gap]) cube([20, 10, 20]);
            }
            temple_hinge_part();
        }
        translate([0,0,-8.6]) cylinder(d=3.4, h=2.2, $fn=24);
        translate([0,0,tk_z[0]-0.1]) cylinder(d=tube_hole_glue, h=tk_z[1]-tk_z[0]+0.2, $fn=fn_fine);
        rotate([0,0, splayed ? -splay : 0]) cubeb([bar_in-0.1, -0.5, -8.6], [bar_in+2.0, 2, -6.6]);
    }
}
module ear_grip_local(side) {        // TPU sleeve: holds the cell in, comfortable behind the ear
    difference() {
        intersection() {
            hull() { yz(bar_in-1.2, ear_t1+0.4) earpiece2d(1.2); yz(bar_in-0.6, ear_t1+1.2) earpiece2d(0.6); }
            ear_frame() translate([-50, 1, -50]) cube(100);
        }
        hull() { yz(bar_in-0.1+0.1, ear_t1-0.8) earpiece2d(-0.1); yz(bar_in+0.1, ear_t1-0.1) earpiece2d(-0.9); }
        ear_frame() translate([-50, -99, -50]) cube(100);
    }
}
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

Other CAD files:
cad/plates/plate_0_tolerance_coupon.3mf
cad/3mf/temple_right.3mf
cad/3mf/ear_grip_left.3mf
cad/stl/ear_grip_left.stl
cad/stl/ear_grip_right.stl
cad/stl/frame.stl
cad/stl/temple_left.stl
cad/stl/temple_right.stl
cad/stl/tolerance_coupon.stl
cad/stl/visor_back.stl
cad/stl/visor_shell.stl
models/ear_grip_left.stl
models/ear_grip_right.stl
models/frame.stl
models/temple_left.stl
models/temple_right.stl
models/visor_back.stl
models/visor_shell.stl

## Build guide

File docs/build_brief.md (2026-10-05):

> **Note:** this is the original v0.1 master brief (camera-free). v0.2 deliberately changes direction: camera passthrough, outward design screens, flip-up visor. See [design_changes.md](design_changes.md) and [requirements.md](requirements.md).

# ADAPTIVE SMART GLASSES — MASTER BUILD BRIEF (paste into a new chat; attach CAD + BOM files)

You are continuing a real, buildable wearable prototype — not a rendering. Read all of this
before changing anything, and review every supplied file first. Act as the combined senior
product, embedded, optical-mechanical, firmware, mobile, industrial-design, electrical,
battery/power, and safety engineer. GOAL: a system that can actually be printed, wired,
programmed, tested, iterated, and worn, that looks far closer to normal eyewear than a headset.

## 0. Non-negotiable invariants (never weaken without an explicit, deliberate design change)
PRIVACY
- CAMERA-FREE. Depth/proximity only, via multi-zone Time-of-Flight (ToF). No image capture.
- NO wake word. NO always-on microphone. NO rolling audio buffer. NO face recognition.
- Microphone receives electrical power ONLY while the physical push-to-talk (PTT) switch is
  held. Firmware has NO other route capable of powering the mic.
- Privacy LED is wired to the switched mic power rail; software cannot drive it independently.
  Mic powered = red LED lit, always.
SAFETY
- The ESP32-S3 is the safety authority even if a media processor is added.
- DRIVE_SAFE disables distracting media at the HARDWARE/control layer (MEDIA_EN = LOW), not by
  hiding video in the app. The phone app can NEVER bypass DRIVE_SAFE.
- Entertainment never overrides driving, battery, thermal, visual, or privacy safety.
- Invalid ToF data must NOT be read as "clear path." GNSS loss while already moving must NOT
  immediately restore media. Fail conservative.
HONESTY
- Never claim a feature works unless the actual hardware/software supports it. The ToF gives
  "object ~0.6 m ahead," NOT "that is a bicycle / a red light" — no semantic vision claimed.

## 1. Architecture at a glance
Phone (heavy AI/ASR/translation/TTS) ⇄ BLE (control/status) + Wi-Fi (audio/media/firmware) ⇄
ESP32-S3 (safety authority, sensors, PTT, audio routing, HUD control) → optional media
processor (Pi-class) for video, gated by MEDIA_EN. Core functions run offline/disconnected.

## 2. Core controller
Seeed Studio XIAO ESP32-S3, NON-Sense version (avoids an unwanted camera). Owns BLE, Wi-Fi,
IMU/ToF/pressure/temperature acquisition, PTT sensing, mic interface, audio routing, HUD
control, battery/power management, driving-safety logic, flight-mode logic, obstacle warnings,
phone link, and final safety-state authority.

## 3. Sensors & environment
- Depth: VL53L5CX 8×8 multi-zone ToF (64 zones), bridge/front-center. Obstacles ahead,
  left/right clearance, closing distance, rapidly-approaching detection. No photographs.
- IMU: ICM-42688-P 6-axis. Head motion, movement classification, driving-detection assist.
  IMU alone never concludes "driving."
- Pressure: BMP390 as CONTEXT only. < ~820 hPa for ~120 s → prompt "Enable Flight Mode?"
  (user confirms). Normal ~820–1080 hPa. Weird readings → diagnostics, not assumptions.
- Ambient temp/humidity: SHT40, in a ventilated outer pod away from skin, battery, regulators,
  and processor heat; calibrate before display.

## 4. Driving detection & DRIVE_SAFE
Fuse PHONE GNSS SPEED + GLASSES IMU. Candidate: speed ≥ ~8.0 m/s (~18 mph) for ~10 s with
motion evidence → DRIVE_SAFE. DRIVE_SAFE disables video, movies, feeds, games, large images,
long visual AI answers, heavy animation (MEDIA_EN LOW). Allows clock, short safety messages,
essential status, basic nav cues, battery warnings, audio interaction, obstacle warnings.
Exit only after speed < ~2.5 m/s (~5.6 mph) for ~30 s. GNSS loss while moving does NOT restore
media. Vehicle testing is done by a passenger/test operator — never debug while driving.

## 5. Flight mode (user-confirmed)
Disable Wi-Fi/media streaming as appropriate; keep local clock, sensors, offline HUD,
downloaded translation, and essential local safety. Follow airline/user Bluetooth rules
rather than assuming Bluetooth must be off.

## 6. Audio (two independent paths)
Bone conduction: 2× ~8 Ω 1 W transducers near mastoid on compliant TPU mounts (no hard clamp).
Open/outward: 2× ~8 Ω 1–2 W micro speakers, directional/open-ear. Amps: 2× MAX98357A I2S
(one bone, one outward), independent enables → BONE / OUTWARD / BOTH / MUTE. App controls the
mix; firmware enforces a safe maximum volume. Safety cues use short recognizable patterns, not
long speech: LOW visual-only → MEDIUM visual+tone → HIGH visual+bone cue → URGENT distinct
bone cue + concise spoken warning.

## 7. Microphone privacy wiring (build exactly this)
DPST momentary PTT button. Pole A: 3.3 V → physical switch → MIC_3V3 → microphone.
Pole B: switch → ESP32 PTT input. Red privacy LED + ~1k resistor powered directly from MIC_3V3.
Voice flow: hold PTT → mic powered → speak → release → mic power removed → captured audio to
phone/local → ASR → AI/translation → response to HUD and/or audio. No wake word.

## 8. Translation
Online: phone/cloud does ASR, translation, AI, TTS. Offline: phone uses downloaded ASR +
translation + TTS packs (English, Spanish, French, German, Italian, Japanese, Korean, Mandarin,
extensible). Never promise every language works fully offline; ship downloadable language packs.

## 9. Display / HUD (optics stay experimental until §12 passes)
Real near-eye optics, NOT an LCD behind mirrored plastic:
MICRO-OLED → collimating/aspheric optic → partially reflective combiner (~30% reflect /
~70% transmit) → eye. Combiner is purchased optical-grade material — never FDM-transparent
plastic. HUD shows time, temp, battery, phone/Wi-Fi state, translation, AI responses, nav,
mic status, audio path, drive-safe + flight-mode indicators, obstacle warnings, notifications,
optional media. Minimal, non-obstructive; never permanently cover central vision.
MONOCULAR FIRST: build one eye, validate focus, eyebox, brightness, combiner angle, display
distance, collimator position, comfort, peripheral vision, alignment — before buying a second
microdisplay. Prototype target 640×400-class micro-OLED in an adjustable housing whose focal
spacing can be changed experimentally.

## 10. Power
Battery: protected 1S LiPo ~1200 mAh, removable/serviceable, away from heat and hard skin
pressure, puncture-protected, reputable cell. Charging: USB-C BQ24074 load-sharing power-path
charger + 10k NTC thermistor bonded to the pack; safe to operate while powered. Regulation:
5 V boost ≥ ~1 A core; media module gets its OWN supply ≥ ~2 A (never run media current through
ESP32-class traces). Real mechanical SPST/DPST main power switch isolating the system from the
battery/load path except circuitry required for safe charging/protection.

## 11. Optional media subsystem (only after core works)
Raspberry Pi Zero 2 W (or a justified better low-power part) for H.264/video, high-res graphics,
image decode, streaming, advanced UI. Target 720p/1080p-class micro-OLED. Path: phone → Wi-Fi →
media computer → micro-OLED controller → display → optics. If ESP32 says MEDIA_EN LOW, video
stops regardless of what the media computer requests.

## 12. Bill of materials (priced; CORE ≈ $172, +HUD ≈ $341 total, +MEDIA ≈ $540 total)
CORE — XIAO ESP32-S3 (~$7.49) · VL53L5CX / SparkFun Qwiic Mini ToF (~$25.95) · ICM-42688-P
(~$15) · BMP390 (~$10.99) · SHT40 (~$5.95) · SPH0645LM4H I2S mic (~$6.95) · 2× MAX98357A
(~$5.95 ea) · 2× 8 Ω 1 W bone transducer (~$8 ea) · 2× 8 Ω 1–2 W micro speaker (~$4 ea) ·
BQ24074 USB-C charger (~$14.95) · protected 1S LiPo 1200 mAh (~$9.95) · TPS61023-class 5 V
boost (~$6) · 10k NTC (~$1) · DPST momentary PTT (~$4) · SPST/DPST main slide switch (~$2) ·
red LED + 1k resistor (~$0.25) · 28–32 AWG silicone wire + JST-SH/Qwiic pigtails (~$10) ·
M2 5/6 mm screws + M2 heat-set inserts (~$8) · 95A TPU + 1–2 mm silicone/foam tape (~$8).
HUD — 2× ~30R/70T optical combiner (~$25 ea) · 640×400-class micro-OLED + driver (~$99;
confirm controller compatibility BEFORE purchase) · 20–25 mm collimating/aspheric lens +
adjustable holder (~$20). Buy second-eye parts only after monocular optics succeed.
MEDIA (optional) — Pi Zero 2 W (~$14.99) · 720p/1080p micro-OLED + controller (~$150) ·
2000–3000 mAh LiPo + 5 V ≥2 A (~$25) · 32 GB A1/A2 microSD (~$7).
Sourcing: keep the priced source URLs from bom.csv; deliver the final BOM as a table with
live links. Confirm every module's real datasheet dimensions before CAD pockets are sized.

## 13. CAD (delivered as parametric OpenSCAD; 17 parts; PETG/ASA structure, TPU 95A grips)
Source: adaptive_smart_glasses.scad + config.scad (all tunable dims) + README_CAD.md +
customization.md + print_manifest.csv. Parts (STL + 3MF): front_frame, temple_left/right,
temple_cover_left/right, ear_grip_left/right, sensor_pod, optics_pod_left/right,
optics_pod_cover, combiner_blank, rear_battery_pod/cover, rear_compute_pod/cover,
decorative_brow_insert. Decorative pieces separate from structural — cosmetics swap without
replacing the frame.
Improvement priorities: reduce frame/temple thickness and mass; size every pocket from REAL
measured modules; FDM tolerance 0.25–0.50 mm/side tuned with coupons; connector + wire
clearance; wire channels + strain relief; stronger hinges with cabling that survives repeated
folding; better balance, nose fit, ear fit, optical adjustment, cover retention; easier
assembly; cooling; serviceability. Do NOT trap dev boards behind rigid rear walls when
Dupont/Qwiic connectors must exit — use edge retention, open-backed supports, rails, clips, or
standoffs with generous clearance. Fasteners M2×5/6 mm + heat-set inserts for repeatedly-opened
covers. Print on Bambu Lab P1S (parts should also fit A1 / A1 Mini where dimensions allow);
minimize supports, choose print orientation intentionally.

## 14. Firmware (modular; ESP-IDF on ESP32-S3)
Modules: power_manager, sensor_manager, imu_service, tof_service, pressure_service,
ambient_service, ptt_audio_service, audio_router, display_service, ble_service, wifi_service,
phone_link, safety_policy, drive_state_machine, flight_mode, hazard_detector, thermal_manager,
battery_manager, diagnostics, firmware_update. Obstacle thresholds: forward object < ~0.8 m →
brief warning; < ~0.45 m → urgent; < ~1.5 m and rapidly closing → urgent; give LEFT/CENTER/
RIGHT when possible; invalid reading ≠ clear path. safety_policy and drive_state_machine are
authoritative over media_enable. Keep host-testable logic separate from hardware drivers.

## 15. Phone app
Pairing, BLE, Wi-Fi session mgmt, battery level, sensor health, temperature, HUD brightness/
themes/color/layout, audio mix (bone/outward/both/mute), AI voice on/off, translation config +
language packs, media casting, firmware update, diagnostics, drive-safe indication, flight-mode
control, privacy + data-retention controls. The app must NEVER bypass DRIVE_SAFE.

## 16. Build phases (bench before frame; monocular before binocular; media last)
1 Bench electronics: ESP32-S3 + IMU + VL53L5CX + BMP390 + SHT40 + PTT mic + one MAX98357A +
  one bone transducer; verify I2C, I2S, sensor detection, PTT, physical mic power gating,
  privacy LED, BLE, basic safety state machine. 2 Power: BQ24074 + protected battery + NTC +
  boost + main switch; test charging, battery temp, current, brownout, power-off, load sharing,
  max audio demand. 3 Frame: print + fit electronics WITHOUT optics; test fit/comfort/balance/
  routing/clearance/PTT location/USB-C access/heat/ear+nose pressure. 4 Depth: mount ToF, zone
  map, test wall/door/person/chair/left/right/dark/reflective/glass/approaching/failure; log
  false pos/neg. 5 One-eye display: tune focus, eyebox, combiner angle, virtual image, bright-
  ness, pupil position. 6 AI/translation: PTT audio → ASR → AI → translation → TTS → HUD + bone,
  then offline packs. 7 Driving safety: fuse GNSS+IMU; verify DRIVE_SAFE, MEDIA_EN low, app
  can't re-enable. 8 Flight/altitude: low pressure only prompts. 9 Media: add processor +
  hi-res display; verify video dies instantly on MEDIA_EN low; measure heat/runtime/Wi-Fi/
  latency. 10 Custom PCB (rigid-flex or small rigid boards + flex) after modules prove out.

## 17. Validation gates (must all pass)
PTT released ⇒ mic physically unpowered. Privacy LED can't activate independent of mic rail.
Battery stays within safe temp/current/voltage. Visual media can't bypass DRIVE_SAFE. GNSS loss
has explicit defined safe behavior. Invalid depth ≠ clear path. Optics don't dangerously obscure
central vision. Audio at safe listening levels. No sharp edges on skin. Hinge cabling survives
repeated folding. Battery never flexes/pinches/punctures/overheats. Frame survives realistic
handling and small drops.

## 18. Deliverable status labels (use on everything)
Mark each subsystem FINISHED / PROTOTYPE-READY / EXPERIMENTAL. Distinguish what the hardware
actually supports today from what is aspirational. Optics and media are EXPERIMENTAL until their
bench tests pass.

## 19. Cost discipline
Low-cost sensors + ESP32 for core; PHONE does expensive AI; no cloud-class compute on the
glasses; Pi/media only if video is needed; one display first; dev modules first, custom PCB
after validation. Optics will remain the most expensive subsystem.

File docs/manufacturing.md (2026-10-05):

# Manufacturing guide (v0.2, one unit)

```
PRINT ──► BENCH (visor electronics) ──► BRICK ──► OPTICS ──► ASSEMBLE ──► SAFETY TEST ──► QA SHEET
```

## 0 · You need
- **Parts:** [`BOM.md`](BOM.md)
- **Tools:**
  - Bambu Lab P1S (or A1 / A1 Mini)
  - Soldering iron + heat-set tip
  - Wire strippers for 30 AWG, multimeter, calipers
  - Razor saw or tube cutter, 4.0 / 4.2 / 4.35 mm drills, conical punch
  - CA glue, Kapton, 1 mm foam tape
- **Software:** OpenSCAD, Bambu Studio, `esptool` (or ESP-IDF 5.5), Raspberry Pi OS on the brick

## 1 · Print
| Plate | File | Material |
|---|---|---|
| 0 | `cad/plates/plate_0_tolerance_coupon.3mf` | PETG. **Print first.** Copy the fits that work into `config.scad`, then run `./tools/build.sh`. |
| 1 | `cad/plates/plate_1_frame_temples_petg.3mf` | PETG, 0.16 mm, 4 walls |
| 2 | `cad/plates/plate_2_visor_petg.3mf` | **Black** PETG (stops light leaking in) |
| 3 | `cad/plates/plate_3_tpu_grips.3mf` | TPU 95A, external spool |

**Post-process:**
- Frame: ream the temple knuckles to 4.35 mm (they turn) and the visor knuckles to 4.2 mm (friction holds the visor up).
- Temples and visor knuckles: drill to 4.05 mm (the tubes are glued here).
- Visor: heat-set 4 M2 inserts in the back bosses.
- Frame: press the 6 × 3 magnet into the brow center.

## 2 · Bench: visor electronics (before anything goes into plastic)
1. Wire the XIAO to both 1.69″ screens, the IMU, the hall switch, the button and the battery divider exactly as in [`pinout.md`](pinout.md). Tie the screen RST pins to 3V3.
2. Flash the firmware:
   ```bash
   pip install esptool
   esptool.py --chip esp32s3 write_flash 0x0 firmware/glasses_mcu/prebuilt/asg_glasses_mcu_merged.bin
   ```
3. The serial monitor should show the self-test: IMU PASS and a battery voltage.
4. Both screens should show animated eyes.
5. Press the button to cycle designs. A magnet near the hall switch toggles visor DOWN/UP.
6. Open the web app's **Glasses** tab, connect, and change the design and text from your phone.

## 3 · Brick
```bash
git clone https://github.com/<you>/adaptive-smart-glasses && cd adaptive-smart-glasses
bash brick/setup_brick.sh                 # OpenCV + the ASG-BRICK hotspot the visor joins
python3 brick/passthrough.py              # camera -> side-by-side 3840x1080 fullscreen
```
- Test on a normal monitor first.
- Unplug the camera: a red LIFT VISOR screen should appear in under 0.25 s.

## 4 · Optics (EXPERIMENTAL)
- Connect the dual micro-OLED kit's HDMI board to the Pi and set 3840×1080. Check the board's supported modes first.
- Measure the eyepiece (diameter, length) and the driver board. Set `eyepiece_d`, `eyepiece_len` and `hdmi_board` in `config.scad`, then rebuild `visor_back` and `visor_shell`.
- Set `ipd` to your pupil distance so the sleeves center on your eyes.

## 5 · Assemble
1. **Earpieces:**
   - Charge both cells to 4.2 V separately.
   - Lay each cell in its bay, leads toward the ear bend.
   - Run the leads along the groove to the temple tube.
2. **Hinges:**
   - Thread the wires first.
   - Glue a tube into each temple knuckle (13.5 mm) and each visor knuckle (12 mm).
   - Push the tubes into the frame knuckles and flare the ends.
   - The right cell's wires cross the brow groove to the left visor tube.
3. **Visor:**
   - Screens into their corner stops, facing out.
   - Camera board behind the lens hole.
   - LED + 1k next to the camera.
   - Switches and button into the crest slots.
   - XIAO + IMU in the bridge, HDMI board on the rails.
   - Hall switch on the back plate, centered, facing the brow magnet.
   - Eyepieces in the back-plate sleeves.
   - Back plate on with 4 × M2×6.
4. **Cable:** HDMI + USB into the crest, zip-tied to the internal bar, then clipped along the left temple.
5. **Finish:** grips over the earpieces, nose pads on.

## 6 · Safety test + QA sheet
| # | Check | Pass when | ☐ |
|---|---|---|---|
| 1 | Self-test | IMU PASS, battery 3.0–4.3 V | ☐ |
| 2 | Designs | Eyes, rings, rainbow, text and off all work from both the button and the app | ☐ |
| 3 | Camera kill | SW2 off: the LED is off and the brick sees no camera | ☐ |
| 4 | Camera LED | On every time the camera has power | ☐ |
| 5 | Stall fail-safe | Unplug the camera: red LIFT VISOR in under 0.25 s | ☐ |
| 6 | Visor up | Both screen pairs go dark. The visor stays up by friction. | ☐ |
| 7 | Hinges | 20 folds of each temple and 20 flips of the visor with battery continuity held | ☐ |
| 8 | Latency | Film a stopwatch through the eyepiece: ≤ 120 ms | ☐ |
| 9 | Comfort | 15 min seated, no hot spots, no pressure points | ☐ |

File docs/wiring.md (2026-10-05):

# Wiring overview (v0.2)

**Every pin is in [`pinout.md`](pinout.md)**, generated from [`../hardware/netlist.csv`](../hardware/netlist.csv). This page explains the rules behind it.

Power and camera privacy

## Rules the wiring enforces
1. **Camera privacy is physical.** VBUS → SW2 → CAM_5V is the camera's only supply. The CAMERA LIVE LED (D1 + R1) sits on that rail. No GPIO touches it.
2. **Only battery wires cross hinges.** Each temple tube carries its cell's BAT+ and GND. The left visor tube carries both pairs. Everything else (screens, camera, flex cables) lives inside the visor and never bends.
3. **The brick powers the heavy parts.** The camera and the micro-OLED board run from the cable's 5 V (power-bank port 2), never from the earpiece cells. The cells only run the XIAO and the design screens.
4. **The XIAO charges the cells.** Cable 5 V goes through a 1N5817 into the XIAO 5V pin, and its charger (≈100 mA) tops up the parallel cells through SW1.

Signals

## Data paths
| Path | Link | Rate |
|---|---|---|
| Camera → brick | USB 2.0 UVC, MJPEG 1080p30 | 30 fps |
| Brick → micro-OLEDs | HDMI, side by side 3840×1080 | 30–60 Hz |
| Visor → brick | Wi-Fi UDP to `10.42.0.1:5005`: head pose, battery, visor state, AR mode (44-byte packet) | 100 Hz |
| Phone ↔ visor | BLE GATT `7a1e0000-…` (design, brightness, text, AR mode, status) | on change / 0.5 Hz |

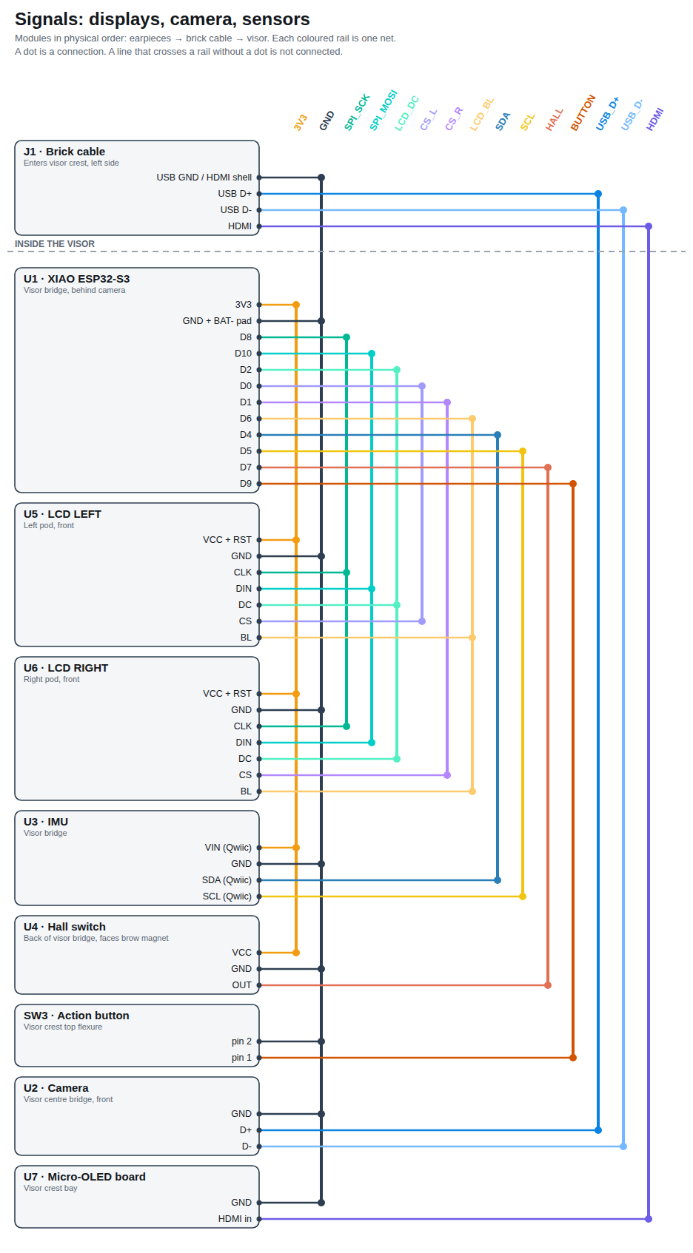
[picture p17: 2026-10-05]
docs/img/wiring_signals.png

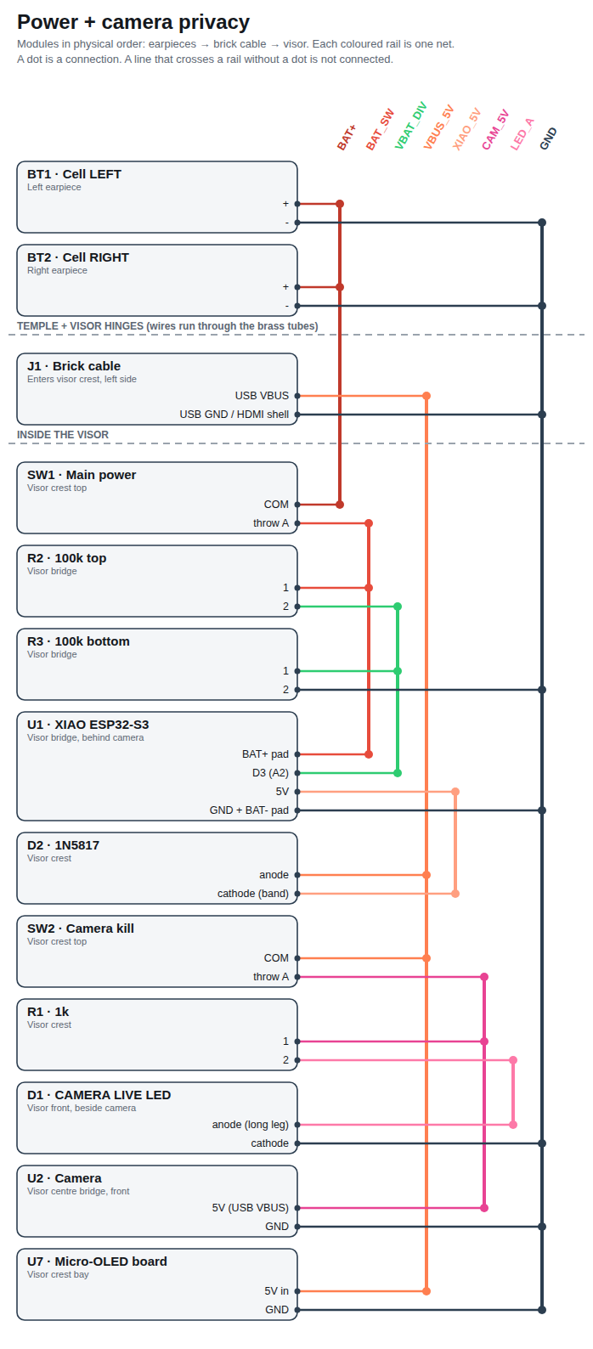
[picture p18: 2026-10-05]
docs/img/wiring_power.png

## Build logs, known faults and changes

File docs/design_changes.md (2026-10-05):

# v0.2: why it looks like this

v0.1 was camera-free with sensor-stuffed temple pods. It was bulky (temple pods 23 × 12 mm) and didn't do what you wanted.
v0.2 follows your direction: **a center camera, two screens per eye (outward designs + inward view), and the Apple Vision Pro / Google approach of moving weight and compute off the face.**

| Decision | Why |
|---|---|
| **Camera passthrough** (inner screens show the camera view) | Your choice. It lets the inside screens "help you see" with zoom, edge highlight and low-light boost, while the outside screens can be fully opaque design screens. |
| **Flip-up visor** on a brow hinge | A passthrough display blinds you when power or the camera fails. Flipping the visor up gives normal glasses in one motion. A hall sensor turns the screens off when it's up. |
| **Everything electronic in the visor** | Only battery wires cross hinges (2 per temple). The display flex cables, camera and screens never bend. |
| **Batteries in the earpieces** | As you asked. They also counterbalance the front-heavy visor. |
| **Pocket brick (Pi 5) for passthrough + AR, phone for control and AI** | Vision Pro puts its battery in a pocket. Here the brick also does the image processing, which an ESP32 cannot. The phone talks to the visor over BLE. |
| **XIAO ESP32-S3 stays the on-glasses chip** | It drives the design screens, reads the IMU, hall sensor, button and battery, and handles BLE and Wi-Fi. It is cheap and already known. |
| **Hardware camera privacy** | SW2 cuts the camera's 5 V. The CAMERA LIVE LED sits on that rail. No face recognition, and no recording by default. |

## Removed since v0.1
ToF depth sensor, BME280, microphone + PTT, 2 audio amps, bone transducer, speaker, bq25185 charger board, HUD tower, combiner.
Audio comes from your phone or earbuds. Depth comes from the camera (later).
Printed parts went from **10 to 7**. Temples went from **23 × 12.4 mm pods to 5 × 10 mm arms**.

## Known trade-offs (and the next step for each)
| Trade-off | Next step |
|---|---|
| Mono passthrough (one camera, same image to both eyes) gives no true depth | Add a stereo pair of cameras at eye spacing (v0.3) |
| 30 fps and an estimated 60–120 ms latency | 38 mm 60 fps camera board, GStreamer zero-copy, or an RK3588 brick |
| 400 mAh in the earpieces covers about 1.5 h of designs-only standby | Passthrough runs from the brick's power bank over the cable |
| About 150 g | Custom flex PCB + 0.49″ panels (option in the BOM) |
| Eyepiece and driver-board sizes not yet confirmed | Measure, set `[MEASURE]` values, rebuild |

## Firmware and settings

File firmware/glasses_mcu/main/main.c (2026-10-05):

// Adaptive Smart Glasses v0.2 — visor MCU firmware (ESP-IDF 5.5, Seeed XIAO ESP32-S3)
// Status: EXPERIMENTAL — compiles cleanly; not yet run on a finished unit.
//   * outward design screens (designs.c)      * phone control over BLE (ble.c)
//   * head pose + state to the brick over Wi-Fi UDP (net.c)
//   * IMU, visor hall switch, action button, battery sense (this file)
// Privacy note: the camera's power is switched by SW2 in hardware and the CAMERA-LIVE LED
// sits on that rail. Nothing in this firmware can power the camera or hide the LED.
#include <stdio.h>
#include <math.h>
#include "freertos/FreeRTOS.h"
#include "freertos/task.h"
#include "driver/gpio.h"
#include "driver/i2c_master.h"
#include "esp_adc/adc_oneshot.h"
#include "esp_adc/adc_cali.h"
#include "esp_adc/adc_cali_scheme.h"
#include "esp_timer.h"
#include "esp_log.h"
#include "nvs_flash.h"
#include "asg.h"

asg_state_t G = { .design = DESIGN_EYES, .brightness = 70, .ar_mode = AR_NORMAL, .text = "HELLO WORLD" };
static const char *TAG = "asg";
static i2c_master_dev_handle_t imu;
static int imu_ok;

// ---------------- IMU: LSM6DSOX @ 0x6A (or 0x6B) ----------------
static esp_err_t imu_wr(uint8_t r, uint8_t v) { uint8_t b[2] = { r, v }; return i2c_master_transmit(imu, b, 2, 20); }
static esp_err_t imu_rd(uint8_t r, uint8_t *d, size_t n) { return i2c_master_transmit_receive(imu, &r, 1, d, n, 20); }
static void imu_init(void) {
    i2c_master_bus_handle_t bus;
    i2c_master_bus_config_t bc = { .i2c_port = I2C_NUM_0, .sda_io_num = PIN_SDA, .scl_io_num = PIN_SCL,
        .clk_source = I2C_CLK_SRC_DEFAULT, .glitch_ignore_cnt = 7, .flags.enable_internal_pullup = true };
    ESP_ERROR_CHECK(i2c_new_master_bus(&bc, &bus));
    for (int a = 0x6A; a <= 0x6B && !imu_ok; a++) {
        if (i2c_master_probe(bus, a, 20) != ESP_OK) continue;
        i2c_device_config_t dc = { .dev_addr_length = I2C_ADDR_BIT_LEN_7, .device_address = a, .scl_speed_hz = 400000 };
        ESP_ERROR_CHECK(i2c_master_bus_add_device(bus, &dc, &imu));
        uint8_t who = 0; imu_rd(0x0F, &who, 1);
        imu_ok = (who == 0x6C);
        ESP_LOGI(TAG, "IMU @0x%02X WHO_AM_I=0x%02X %s", a, who, imu_ok ? "OK" : "unexpected");
    }
    if (!imu_ok) { ESP_LOGW(TAG, "IMU not found: check Qwiic cable"); return; }
    imu_wr(0x12, 0x44);   // CTRL3_C: BDU + auto-increment
    imu_wr(0x10, 0x60);   // CTRL1_XL: 416 Hz, +-2 g
    imu_wr(0x11, 0x60);   // CTRL2_G : 416 Hz, 250 dps
}
static void imu_task(void *arg) {
    int64_t last = esp_timer_get_time(); int n = 0;
    while (1) {
        if (imu_ok) {
            uint8_t d[12]; int16_t r[6];
            if (imu_rd(0x22, d, 12) == ESP_OK) {
                for (int i = 0; i < 6; i++) r[i] = (int16_t)(d[2 * i] | d[2 * i + 1] << 8);
                for (int i = 0; i < 3; i++) { G.gyr[i] = r[i] * 0.00875f; G.acc[i] = r[3 + i] * 0.000061f; }
                int64_t now = esp_timer_get_time(); float dt = (now - last) / 1e6f; last = now;
                // complementary filter (axes as mounted in the visor bridge — verify signs on the bench)
                float ap = atan2f(-G.acc[0], sqrtf(G.acc[1] * G.acc[1] + G.acc[2] * G.acc[2])) * 57.2958f;
                float ar = atan2f(G.acc[1], G.acc[2]) * 57.2958f;
                G.pitch = 0.98f * (G.pitch + G.gyr[1] * dt) + 0.02f * ap;
                G.roll  = 0.98f * (G.roll  + G.gyr[0] * dt) + 0.02f * ar;
                G.yaw  += G.gyr[2] * dt;
            }
        }
        if (++n % 2 == 0) net_send_pose();                              // 100 Hz to the brick
        vTaskDelay(pdMS_TO_TICKS(5));                                   // 200 Hz
    }
}

// ---------------- battery sense: D3 = VBAT/2 ----------------
static adc_oneshot_unit_handle_t adc; static adc_cali_handle_t cal;
static void vbat_init(void) {
    adc_oneshot_unit_init_cfg_t uc = { .unit_id = ADC_UNIT_1 }; adc_oneshot_new_unit(&uc, &adc);
    adc_oneshot_chan_cfg_t cc = { .atten = ADC_ATTEN_DB_12, .bitwidth = ADC_BITWIDTH_DEFAULT };
    adc_oneshot_config_channel(adc, ADC_CHANNEL_3, &cc);
    adc_cali_curve_fitting_config_t cf = { .unit_id = ADC_UNIT_1, .chan = ADC_CHANNEL_3, .atten = ADC_ATTEN_DB_12, .bitwidth = ADC_BITWIDTH_DEFAULT };
    if (adc_cali_create_scheme_curve_fitting(&cf, &cal) != ESP_OK) cal = NULL;
}
static int vbat_read_mv(void) {
    int raw, mv, sum = 0;
    for (int i = 0; i < 8; i++) { adc_oneshot_read(adc, ADC_CHANNEL_3, &raw);
        if (cal) { adc_cali_raw_to_voltage(cal, raw, &mv); } else mv = raw * 3100 / 4095; sum += mv; }
    return 2 * sum / 8;
}

void app_main(void) {
    esp_err_t e = nvs_flash_init();
    if (e == ESP_ERR_NVS_NO_FREE_PAGES || e == ESP_ERR_NVS_NEW_VERSION_FOUND) { nvs_flash_erase(); nvs_flash_init(); }
    gpio_config_t in = { .pin_bit_mask = (1ULL << PIN_HALL) | (1ULL << PIN_BUTTON), .mode = GPIO_MODE_INPUT, .pull_up_en = 1 };
    gpio_config(&in);
    imu_init();
    vbat_init();
    G.vbat_mv = vbat_read_mv();
    G.visor_up = gpio_get_level(PIN_HALL);

    printf("\n===== ASG v0.2 self-test =====\n");
    printf("  [%s] IMU LSM6DSOX\n", imu_ok ? "PASS" : "FAIL");
    printf("  [%s] Battery %d mV (expect 3000-4300; ~0 = switch off or USB only)\n", (G.vbat_mv > 3000 && G.vbat_mv < 4300) ? "PASS" : "WARN", G.vbat_mv);
    printf("  [INFO] Visor is %s (hall)\n", G.visor_up ? "UP" : "DOWN");
    printf("  Watch both outward screens: animated eyes should appear.\n\n");

    designs_start();
    ble_start();
    net_start();
    xTaskCreatePinnedToCore(imu_task, "imu", 4096, NULL, 5, NULL, 0);

    int held = 0, last_btn = 1; int64_t t_status = 0;
    while (1) {                                                         // 20 ms UI loop
        int up = gpio_get_level(PIN_HALL);
        if (up != G.visor_up) { G.visor_up = up; ESP_LOGI(TAG, "visor %s", up ? "UP" : "DOWN"); ble_notify_status(); }
        int b = gpio_get_level(PIN_BUTTON);
        if (b == 0) held++;
        if (b == 1 && last_btn == 0) {                                  // release
            if (held >= 50)      G.design = DESIGN_OFF;                 // >= 1 s: designs off (privacy / battery)
            else if (held >= 2)  G.design = (G.design + 1) % DESIGN_COUNT;
            held = 0; ble_notify_status();
        }
        last_btn = b;
        if (esp_timer_get_time() > t_status) {
            G.vbat_mv = vbat_read_mv(); ble_notify_status();
            t_status = esp_timer_get_time() + 2000000;
        }
        vTaskDelay(pdMS_TO_TICKS(20));
    }
}

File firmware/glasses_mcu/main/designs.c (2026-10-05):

// Outward "design" screens: two ST7789 LCDs on one SPI bus, rendered in 40-line bands.
#include <math.h>
#include <string.h>
#include "freertos/FreeRTOS.h"
#include "freertos/task.h"
#include "freertos/semphr.h"
#include "driver/spi_master.h"
#include "driver/ledc.h"
#include "esp_lcd_panel_io.h"
#include "esp_lcd_panel_vendor.h"
#include "esp_lcd_panel_ops.h"
#include "esp_timer.h"
#include "esp_heap_caps.h"
#include "esp_random.h"
#include "esp_log.h"
#include "asg.h"
#include "font6x8.h"

#define BAND 40
static const char *TAG = "designs";
static esp_lcd_panel_handle_t panel[2];
static uint16_t *buf[2];
static SemaphoreHandle_t done;

static bool on_done(esp_lcd_panel_io_handle_t io, esp_lcd_panel_io_event_data_t *e, void *ctx) {
    BaseType_t hp = pdFALSE; xSemaphoreGiveFromISR(done, &hp); return hp == pdTRUE;
}
static inline uint16_t rgb(float r, float g, float b) {               // 0..1 floats -> byte-swapped RGB565
    int R = r < 0 ? 0 : r > 1 ? 31 : (int)(r * 31), Gc = g < 0 ? 0 : g > 1 ? 63 : (int)(g * 63), B = b < 0 ? 0 : b > 1 ? 31 : (int)(b * 31);
    uint16_t c = (R << 11) | (Gc << 5) | B; return (c >> 8) | (c << 8);
}
static uint16_t hsv(float h, float s, float v) {
    h = fmodf(h, 360.f); if (h < 0) h += 360.f;
    float c = v * s, x = c * (1 - fabsf(fmodf(h / 60.f, 2) - 1)), m = v - c, r, g, b;
    if (h < 60) { r = c; g = x; b = 0; } else if (h < 120) { r = x; g = c; b = 0; } else if (h < 180) { r = 0; g = c; b = x; }
    else if (h < 240) { r = 0; g = x; b = c; } else if (h < 300) { r = x; g = 0; b = c; } else { r = c; g = 0; b = x; }
    return rgb(r + m, g + m, b + m);
}

void designs_backlight(uint8_t pct) {
    ledc_set_duty(LEDC_LOW_SPEED_MODE, LEDC_CHANNEL_0, (1023 * pct) / 100);
    ledc_update_duty(LEDC_LOW_SPEED_MODE, LEDC_CHANNEL_0);
}

// ---------- design pixel functions (eye: 0 = wearer-left screen, 1 = right) ----------
static float look_x, look_y, blink;   // updated once per frame

static uint16_t px_eyes(int x, int y, int eye, float t) {
    float cx = LCD_W / 2.f, cy = LCD_H / 2.f, dx = x - cx, dy = y - cy;
    float lid = 70.f * (1.f - blink);                                   // eyelid half-opening
    if (fabsf(dy) > lid * sqrtf(fmaxf(0, 1 - (dx * dx) / (118.f * 118.f)))) return rgb(0.05f, 0.05f, 0.07f);
    float ix = dx - look_x * 38.f, iy = dy - look_y * 22.f;          // both eyes look the same way
    float d = sqrtf(ix * ix + iy * iy);
    if (d < 17) return (ix + 6) * (ix + 6) + (iy + 7) * (iy + 7) < 30 ? rgb(1, 1, 1) : rgb(0.02f, 0.02f, 0.03f);
    if (d < 46) { float k = d / 46.f; return rgb(0.05f + 0.1f * k, 0.55f + 0.25f * k, 0.75f + 0.2f * k); }
    return rgb(0.93f, 0.93f, 0.95f);
}
static uint16_t px_rings(int x, int y, int eye, float t) {
    float dx = x - LCD_W / 2.f, dy = y - LCD_H / 2.f, d = sqrtf(dx * dx + dy * dy);
    float v = 0.5f + 0.5f * sinf(d * 0.12f - t * 5.f);
    return hsv(200 + 80 * sinf(t * 0.5f) + d * 0.6f, 0.9f, v);
}
static uint16_t px_rainbow(int x, int y, int eye, float t) {
    return hsv((x + eye * LCD_W) * 0.8f + y * 0.6f + t * 90.f, 0.85f, 1.0f);
}
static int text_px(int vx, int y, float t) {                           // scrolling text, 4x scaled font, spans both screens
    int len = strlen(G.text); if (!len) return 0;
    const int S = 4, CW = 6 * S, total = len * CW + 2 * LCD_W;
    int sx = (vx + (int)(t * 120.f)) % total - 2 * LCD_W + LCD_W;      // scroll right->left
    int ty = y - (LCD_H - 8 * S) / 2;
    if (sx < 0 || ty < 0 || ty >= 8 * S) return 0;
    int ci = sx / CW, col = (sx % CW) / S, row = ty / S;
    if (ci >= len || col >= 6) return 0;
    unsigned char c = G.text[ci]; if (c < 32 || c > 126) c = '?';
    return (FONT6x8[c - 32][col] >> row) & 1;
}
static uint16_t px_text(int x, int y, int eye, float t) {
    int vx = eye == 0 ? x : x + LCD_W;                                 // wearer-left screen shows the start
    return text_px(vx, y, t) ? hsv(t * 40.f + x, 0.7f, 1.0f) : rgb(0, 0, 0);
}

static void render(int eye, float t) {
    for (int y0 = 0; y0 < LCD_H; y0 += BAND) {
        uint16_t *b = buf[(y0 / BAND) & 1];
        xSemaphoreTake(done, pdMS_TO_TICKS(100));                       // this buffer's last transfer has finished
        for (int y = 0; y < BAND; y++) for (int x = 0; x < LCD_W; x++) {
            uint16_t c;
            switch (G.design) {
                case DESIGN_EYES:    c = px_eyes(x, y0 + y, eye, t); break;
                case DESIGN_RINGS:   c = px_rings(x, y0 + y, eye, t); break;
                case DESIGN_RAINBOW: c = px_rainbow(x, y0 + y, eye, t); break;
                case DESIGN_TEXT:    c = px_text(x, y0 + y, eye, t); break;
                default:             c = 0; break;
            }
            b[y * LCD_W + x] = c;
        }
        esp_lcd_panel_draw_bitmap(panel[eye], 0, y0, LCD_W, y0 + BAND, b);
    }
}

static void lcd_init(void) {
    spi_bus_config_t bus = { .sclk_io_num = PIN_SCK, .mosi_io_num = PIN_MOSI, .miso_io_num = -1,
                             .quadwp_io_num = -1, .quadhd_io_num = -1, .max_transfer_sz = LCD_W * BAND * 2 + 16 };
    ESP_ERROR_CHECK(spi_bus_initialize(SPI2_HOST, &bus, SPI_DMA_CH_AUTO));
    const gpio_num_t cs[2] = { PIN_CS_L, PIN_CS_R };
    for (int i = 0; i < 2; i++) {
        esp_lcd_panel_io_handle_t io;
        esp_lcd_panel_io_spi_config_t ioc = { .dc_gpio_num = PIN_LCD_DC, .cs_gpio_num = cs[i], .pclk_hz = 40 * 1000 * 1000,
            .lcd_cmd_bits = 8, .lcd_param_bits = 8, .spi_mode = 0, .trans_queue_depth = 2, .on_color_trans_done = on_done };
        ESP_ERROR_CHECK(esp_lcd_new_panel_io_spi((esp_lcd_spi_bus_handle_t)SPI2_HOST, &ioc, &io));
        esp_lcd_panel_dev_config_t pc = { .reset_gpio_num = -1, .rgb_ele_order = LCD_RGB_ELEMENT_ORDER_RGB, .bits_per_pixel = 16 };
        ESP_ERROR_CHECK(esp_lcd_new_panel_st7789(io, &pc, &panel[i]));
        esp_lcd_panel_reset(panel[i]);                                  // software reset (RST tied to 3V3)
        esp_lcd_panel_init(panel[i]);
        esp_lcd_panel_invert_color(panel[i], true);
        esp_lcd_panel_swap_xy(panel[i], true);                          // landscape
        esp_lcd_panel_mirror(panel[i], i == 0, i != 0);                 // [MEASURE] flip per mounting
        esp_lcd_panel_set_gap(panel[i], 20, 0);                         // 240x280 glass in 240x320 RAM
        esp_lcd_panel_disp_on_off(panel[i], true);
    }
    ledc_timer_config_t tc = { .speed_mode = LEDC_LOW_SPEED_MODE, .duty_resolution = LEDC_TIMER_10_BIT,
                               .timer_num = LEDC_TIMER_0, .freq_hz = 5000, .clk_cfg = LEDC_AUTO_CLK };
    ledc_timer_config(&tc);
    ledc_channel_config_t cc = { .gpio_num = PIN_LCD_BL, .speed_mode = LEDC_LOW_SPEED_MODE, .channel = LEDC_CHANNEL_0,
                                 .timer_sel = LEDC_TIMER_0, .duty = 0, .hpoint = 0 };
    ledc_channel_config(&cc);
}
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

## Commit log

2026-10-02 Adaptive Smart Glasses v0.1.0: open-hardware prototype
    [adaptive_smart_glasses.scad, bom.csv, bom_original.csv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]
2026-10-02 Update design
    [combiner_arm.3mf, combiner_arm.stl, display_slider.3mf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]
2026-10-05 v0.2: camera-passthrough glasses, flip-up visor, outward design screens
    [adaptive_smart_glasses.scad, bom.csv, combiner_arm.3mf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]
